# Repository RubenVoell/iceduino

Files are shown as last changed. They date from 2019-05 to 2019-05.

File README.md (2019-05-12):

# A ICE40HX4k Breakout for educational purposes

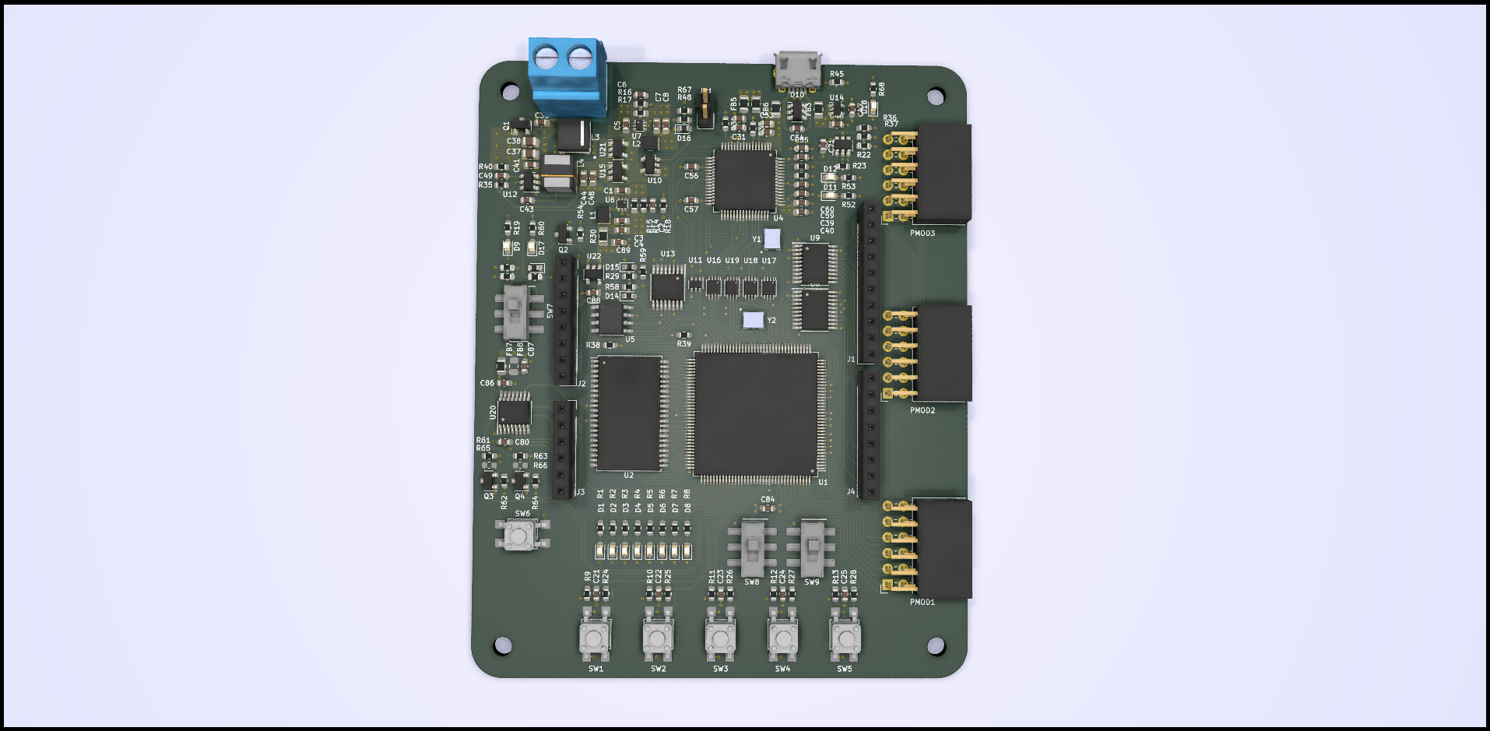
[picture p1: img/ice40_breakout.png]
Rendering of the iCE40HX4K breakout board


The basic idea behind this project is to create a simple breakout of an ICE40 FPGA with some LEDs and Buttons to interact with the FPGA and enough resources to run a simple softcore, like a small RISC-V core. Therefore a SRAM will be added in case the internal memory blocks are not big enough, The configuration SPI flash may be used to store programm data for the softcore. So this board can be used for teaching basic FPGA, microcontroller and CPU architecture topics.

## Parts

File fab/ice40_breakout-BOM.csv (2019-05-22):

Reference | Quantity | Value | Footprint | Datasheet | Description | Digikey | Mfg Name | Mfg Part Num | Spec | DNP | f
C1 C3 C5 C7 C8 C52 C50 C83 C4 C89 C84 C90 C40 C31 C33 C55 C54 C65 C87 C88 C92 C91 | 22 | 10 uF 6,3 V | Capacitor_SMD:C_0603_1608Metric | ~ | CAP CER 10UF 6.3V X5R 0603 | 1276-1119-1-ND | Samsung Electro-Mechanics | CL10A106MQ8NNNC | Any
C17 C18 C19 C20 C53 C51 C16 C15 C14 C13 C12 C11 C10 C9 C43 C21 C22 C23 C24 C25 C42 C74 C45 C85 C39 C30 C32 C66 C56 C57 C58 C59 C60 C64 C67 C68 C69 C71 C72 C70 C61 C62 C63 C77 C78 C75 C76 C81 C82 C79 C27 C28 C29 C26 C73 C86 C80 | 57 | 100nF 6,3 V | Capacitor_SMD:C_0603_1608Metric | ~ | CAP CER 0.1UF 50V X7R 0603 | 1276-1000-1-ND | Samsung Electro-Mechanics | CL10B104KB8NNNC | Any
C2 C6 C49 | 3 | 10pF 6,3 V | Capacitor_SMD:C_0603_1608Metric | ~ | CAP CER 10PF 50V C0G/NP0 0603 | 1276-1027-1-ND | Samsung Electro-Mechanics | CL10C100JB8NNNC | Any
C34 C37 C38 | 3 | 10 uF 25 V | Capacitor_SMD:C_0805_2012Metric | ~ | CAP CER 10UF 25V X5R 0805 | 1276-2891-1-ND | Samsung Electro-Mechanics | CL21A106KAYNNNE | Any
C35 C36 C41 | 3 | 100nF 25 V | Capacitor_SMD:C_0603_1608Metric | ~ | CAP CER 0.1UF 50V X7R 0603 | 1276-1000-1-ND | Samsung Electro-Mechanics | CL10B104KB8NNNC | Any
C47 C46 | 2 | 1 uF 16 V | Capacitor_SMD:C_0603_1608Metric | ~ | CAP CER 1UF 16V X7R 0603 | 1276-6524-1-ND | Samsung Electro-Mechanics | CL10B105MO8NNWC | Any
C48 C44 | 2 | 22 uF 6,3 V | Capacitor_SMD:C_0603_1608Metric | ~ | CAP CER 22UF 6.3V X5R 0603 | 490-7611-1-ND | Murata Electronics North America | GRM188R60J226MEA0D | Any
D10 | 1 | AOZ8904CIL | Package_TO_SOT_SMD:SOT-23-6 | http://aosmd.com/res/data_sheets/AOZ8904CIL.pdf | TVS DIODE 5.5V 18V SOT23-6 | 785-1755-1-ND | Alpha & Omega Semiconductor Inc. | AOZ8904CIL | Spec
D11 | 1 | RX LED | LED_SMD:LED_0603_1608Metric | ~ | LED RED DIFFUSED 1608 SMD | SML-D12U1WT86CT-ND | Rohm Semiconductor | SML-D12U1WT86 | Any
D12 | 1 | TX LED | LED_SMD:LED_0603_1608Metric | ~ | LED RED DIFFUSED 1608 SMD | SML-D12U1WT86CT-ND | Rohm Semiconductor | SML-D12U1WT86 | Any
D13 D16 D14 D15 D19 | 5 | CDBU5020 | Diode_SMD:D_0603_1608Metric | http://www.comchiptech.com/admin/files/product/CDBU0520-HF-RevA797161.pdf | DIODE SCHOTTKY 20V 500MA 0603 | 641-1332-1-ND | Comchip Technology | CDBU0520 | Any
D17 | 1 | DONE | LED_SMD:LED_0603_1608Metric | ~ | LED RED DIFFUSED 1608 SMD | SML-D12U1WT86CT-ND | Rohm Semiconductor | SML-D12U1WT86 | Any
D18 | 1 | USB ON LED | LED_SMD:LED_0603_1608Metric | ~ | LED RED DIFFUSED 1608 SMD | SML-D12U1WT86CT-ND | Rohm Semiconductor | SML-D12U1WT86 | Any
D9 D1 D2 D3 D4 D5 D6 D7 D8 | 9 | LED_ALT | LED_SMD:LED_0603_1608Metric | ~ | LED RED DIFFUSED 1608 SMD | SML-D12U1WT86CT-ND | Rohm Semiconductor | SML-D12U1WT86 | Any
FB1 FB2 FB4 FB5 FB3 FB6 FB7 FB8 | 8 | 330 Ohm | Resistor_SMD:R_0805_2012Metric | https://product.tdk.com/info/en/catalog/datasheets/beads_commercial_power_mpz2012_en.pdf | FERRITE BEAD 330 OHM 0805 1LN | 445-1569-1-ND | TDK Corporation | MPZ2012S331AT000 | Spec
H1 H2 H3 H4 | 4 | MountingHole | MountingHole:MountingHole_3mm | ~
J1 | 1 | Conn_01x10 | Connector_PinSocket_2.54mm:PinSocket_1x10_P2.54mm_Vertical | ~ | CONN HDR 10POS 0.1 GOLD PCB | 732-2859-ND | Wurth Electronics Inc. | 61301011821 | Any
J2 J4 | 2 | Conn_01x08 | Connector_PinSocket_2.54mm:PinSocket_1x08_P2.54mm_Vertical | ~ | CONN HDR 8POS 0.1 GOLD PCB | S7041-ND | Sullins Connector Solutions | PPPC081LFBN-RC | Any
J3 | 1 | Conn_01x06 | Connector_PinSocket_2.54mm:PinSocket_1x06_P2.54mm_Vertical | ~ | CONN HDR 6POS 0.1 GOLD PCB | S7039-ND | Sullins Connector Solutions | PPPC061LFBN-RC | Any
J5 | 1 | USB_B_Micro | footprints:Amphenol_microUSB_B_footprint | http://www.amphenol-icc.com/media/wysiwyg/files/drawing/10118194.pdf | CONN RCPT USB2.0 MICRO B SMD R/A | 609-4618-1-ND | Amphenol ICC (FCI) | 10118194-0001LF | Spec
J6 | 1 | 7-17 V IN | TerminalBlock:TerminalBlock_bornier-2_P5.08mm | https://www.cui.com/product/resource/digikeypdf/tb007-508.pdf | ERMINAL BLOCK, SCREW TYPE, 5.08 | 102-6203-ND | CUI Inc. | TB007-508-02BE
JP1 | 1 | VBUS_EN | Connector_PinHeader_2.54mm:PinHeader_1x02_P2.54mm_Vertical | ~
L1 L2 | 2 | 1u | footprints:L_1008_2520Metric_2.5x2mm_footprint | https://www.yuden.co.jp/productdata/catalog/wound10_e.pdf | FIXED IND 1UH 2.7A 59 MOHM SMD | 587-3225-1-ND | Taiyo Yuden | MAMK2520T1R0M | Spec
L3 | 1 | L_DLW5BTM | footprints:L_Murata_DLW5BTM_5.00x5.00mm_footprint | https://www.murata.com/en-us/products/productdata/8796761587742/EFLC0025.pdf | CMC 5A 2LN 250 OHM SMD | 490-11111-1-ND | Murata Electronics North America | DLW5BTM251SQ2L | Spec
L4 | 1 | 4,7 uH | Inductor_SMD:L_Taiyo-Yuden_NR-50xx | ~ | FIXED IND 4.7UH 3.1A 37.7 MOHM | 587-2373-1-ND | Taiyo Yuden | NR5040T4R7N | Spec
PMOD2 PMOD3 PMOD1 | 3 | Conn_02x06_Odd_Even | Connector_PinSocket_2.54mm:PinSocket_2x06_P2.54mm_Horizontal | ~ | CONN HDR 12POS 0.1 GOLD PCB R/A | S5559-ND | Sullins Connector Solutions | PPPC062LJBN-RC | Any
Q1 | 1 | DMP3099L-7 | Package_TO_SOT_SMD:SOT-23 | https://www.diodes.com/assets/Datasheets/DMP3099L.pdf | MOSFET P-CH 30V SOT23 | DMP3099L-7DICT-ND | Diodes Incorporated | DMP3099L-7 | Spec
Q2 Q4 Q3 | 3 | Q_NMOS_GSD | Package_TO_SOT_SMD:SOT-23 | https://www.diodes.com/assets/Datasheets/DMN65D8L.pdf | MOSFET N-CH 60V 310MA SOT23 | DMN65D8L-7DICT-ND | Diodes Incorporated | DMN65D8L-7 | Spec
R14 R15 | 2 | 100k 1% | Resistor_SMD:R_0603_1608Metric | ~ | RES SMD 100K OHM 1% 1/10W 0603 | 311-100KHRCT-ND | Yageo | RC0603FR-07100KL | Any
R16 | 1 | 220k 1% | Resistor_SMD:R_0603_1608Metric | ~ | RES SMD 220K OHM 1% 1/10W 0603 | 311-220KHRCT-ND | Yageo | RC0603FR-07220KL | Any
R17 | 1 | 48,7k 1% | Resistor_SMD:R_0603_1608Metric | ~ | RES SMD 48.7K OHM 1% 1/10W 0603 | 311-48.7KHRCT-ND | Yageo | RC0603FR-0748K7L | Any
R18 R47 R48 R67 R20 R21 R22 R43 R44 R38 R39 R37 R45 R59 R58 R29 R54 R71 | 18 | 10k | Resistor_SMD:R_0603_1608Metric | ~ | RES 10K OHM 5% 1/10W 0603 | RMCF0603JT10K0CT-ND | Stackpole Electronics Inc | RMCF0603JT10K0 | Any
R19 R1 R2 R3 R4 R5 R6 R7 R8 R52 R53 R68 R60 | 13 | 560 | Resistor_SMD:R_0603_1608Metric | ~ | RES 560 OHM 5% 1/8W 0603 | 2019-RK73B1JTTD561JCT-ND | KOA Speer Electronics, Inc. | RK73B1JTTD561J | Any
R23 R34 | 2 | 2,2k | Resistor_SMD:R_0603_1608Metric | ~ | RES SMD 2.2K OHM 1% 1/10W 0603 | 311-2.20KHRCT-ND | Yageo | RC0603FR-072K2L | Any
R24 R25 R26 R27 R28 R56 R57 | 7 | 470 | Resistor_SMD:R_0603_1608Metric | ~ | RES 470 OHM 5% 1/10W 0603 | RMCF0603JT470RCT-ND | Stackpole Electronics Inc | RMCF0603JT470R | Any
R30 | 1 | 0 | Resistor_SMD:R_0805_2012Metric | ~ | RES SMD 0 OHM JUMPER 1/8W 0805 | 311-0.0ARCT-ND | Yageo | RC0805JR-070RL | Any
R33 | 1 | 12k | Resistor_SMD:R_0603_1608Metric | ~ | RES SMD 12K OHM 5% 1/10W 0603 | 311-12KGRCT-ND | Yageo | RC0603JR-0712KL | Any
R35 | 1 | 54k9 1% | Resistor_SMD:R_0603_1608Metric | ~ | RES SMD 54.9K OHM 1% 1/10W 0603 | 311-54.9KHRCT-ND | Yageo | RC0603FR-0754K9L | Any
R36 | 1 | 4k7 | Resistor_SMD:R_0603_1608Metric | ~ |  |  |  |  |  | DNP
R40 | 1 | 10k 1% | Resistor_SMD:R_0603_1608Metric | ~ | RES SMD 10K OHM 1% 1/10W 0603 | 311-10.0KHRCT-ND | Yageo | RC0603FR-0710KL | Any
R42 R41 | 2 | 100 | Resistor_SMD:R_0603_1608Metric | ~ | RES 100 OHM 1% 1/10W 0603 | RMCF0603FT100RCT-ND | Stackpole Electronics Inc | RMCF0603FT100R | Any
R46 | 1 | 33k | Resistor_SMD:R_0603_1608Metric | ~ | RES SMD 33K OHM 5% 1/10W 0603 | 311-33KGRCT-ND | Yageo | RC0603JR-0733KL | Any
R49 | 1 | 22k | Resistor_SMD:R_0603_1608Metric | ~ | RES SMD 22K OHM 1% 1/10W 0603 | 311-22.0KHRCT-ND | Yageo | RC0603FR-0722KL | Any
R55 | 1 | 270k 1% | Resistor_SMD:R_0603_1608Metric | ~ | RES SMD 270K OHM 1% 1/10W 0603 | 311-270KHRCT-ND | Yageo | RC0603FR-07270KL | Any
R65 R66 | 2 | 0 | Resistor_SMD:R_0603_1608Metric | ~ |  |  |  |  |  | Do Not Place
R69 | 1 | 30k 1% | Resistor_SMD:R_0603_1608Metric | ~ | RES SMD 30K OHM 1% 1/10W 0603 | 311-30.0KHRCT-ND | Yageo | RC0603FR-0730KL | Any
R70 | 1 | 1k | Resistor_SMD:R_0603_1608Metric | ~ | RES SMD 1K OHM 5% 1/10W 0603 | 311-1.0KGRCT-ND | Yageo | RC0603JR-071KL | Any
R9 R11 R12 R13 R10 R50 R51 R31 R32 R63 R64 R61 R62 | 13 | 4,7k | Resistor_SMD:R_0603_1608Metric | ~ | RES 4.7K OHM 5% 1/10W 0603 | RMCF0603JT4K70CT-ND | Stackpole Electronics Inc | RMCF0603JT4K70 | Any
RV1 RV2 | 2 | CG0603MLA-18KE | Resistor_SMD:R_0603_1608Metric | https://www.bourns.com/docs/Product-Datasheets/MLA.pdf | VARISTOR 22V 30A 0603 | CG0603MLA-18KECT-ND | Bourns Inc. | CG0603MLA-18KE | Spec
SW3 SW4 SW5 SW2 SW1 SW6 | 6 | SW_Push | footprints:SW_SPST_TL3305A | http://spec_sheets.e-switch.com/specs/P010468.pdf | SWITCH TACTILE SPST-NO 50MA 12V | EG5350CT-ND | E-Switch | TL3305AF160QG | Spec
SW7 SW8 SW9 | 3 | JS202011SCQN | footprints:SW_SLIDE_DPDT_Slide_CK_JS202011SCQN_W3mm_P2.5mm_footprint | https://www.ckswitches.com/media/1422/js.pdf | SWITCH SLIDE DPDT 300MA 6V | 401-2002-1-ND | C&K | JS202011SCQN | Spec
U1 | 1 | ICE40HX4K-TQ144 | Package_QFP:TQFP-144_20x20mm_P0.5mm |  | IC FPGA 107 I/O 144TQFP | 220-1572-ND | Lattice Semiconductor Corporation | ICE40HX4K-TQ144 | Spec
U10 U21 U15 U22 U23 | 5 | MAX40200AUK | Package_TO_SOT_SMD:SOT-23-5 | https://datasheets.maximintegrated.com/en/ds/MAX40200.pdf | IC DIODE CURRENT SWITCH SOT23-5 | MAX40200AUK+TCT-ND | Maxim Integrated | MAX40200AUK+T | Spec
U11 | 1 | SN74LVC2G07DCKR | Package_TO_SOT_SMD:SOT-363_SC-70-6 | http://www.ti.com/lit/ds/symlink/sn74lvc2g07.pdf | IC BUF NON-INVERT 5.5V SC70-6 | 296-13495-1-ND | Texas Instruments | SN74LVC2G07DCKR | Spec
U12 | 1 | TPS562201 | Package_TO_SOT_SMD:SOT-23-6 | http://www.ti.com/lit/ds/symlink/tps562201.pdf | Buck Switching Regulator IC Positive Adjustable 0.768V 1 Output 2A SOT-23-6 Thin, TSOT-23-6 | 296-44397-1-ND | Texas Instruments | TPS562201DDCR | Spec
U13 | 1 | SN74AXC4T245PWR | Package_SO:TSSOP-16_4.4x5mm_P0.65mm | http://www.ti.com/lit/ds/symlink/sn74axc4t245.pdf | LOGIC GATES AND INVERTERS | 296-53472-1-ND | Texas Instruments | SN74AXC4T245PWR | Spec
U14 | 1 | MIC5365-3.3YC5 | Package_TO_SOT_SMD:SOT-353_SC-70-5 | http://ww1.microchip.com/downloads/en/DeviceDoc/mic5365.pdf | IC REG LINEAR 3.3V 150MA SC70-5 | 576-3193-1-ND | Microchip Technology | MIC5365-3.3YC5-TR | Spec
U16 U17 U19 U18 | 4 | SN74LVC2T45DCUR | Package_SO:VSSOP-8_2.4x2.1mm_P0.5mm | http://www.ti.com/lit/ds/symlink/sn74lvc2t45.pdf | IC TRNSLTR BIDIRECTIONAL US8 | 296-17014-1-ND | Texas Instruments | SN74LVC2T45DCUR | Spec
U2 | 1 | IS61WV5128EDBLL-10TLI | Package_SO:TSOP-II-44_10.16x18.41mm_P0.8mm | http://www.issi.com/WW/pdf/61-64WV5128EDBLL.pdf | C SRAM 4M PARALLEL 44TSOP2 | 706-1147-ND | ISSI, Integrated Silicon Solution Inc | IS61WV5128EDBLL-10TLI | Spec
U20 | 1 | MAX11614 | Package_SO:QSOP-16_3.9x4.9mm_P0.635mm | https://datasheets.maximintegrated.com/en/ds/MAX11612-MAX11617.pdf | IC ADC SERIAL 12BIT 8CH 16-QSOP | MAX11614EEE+-ND | Maxim Integrated | MAX11614EEE+ | Spec
U3 | 1 | 93LCxxBT-I_OT | Package_TO_SOT_SMD:SOT-23-6 | http://ww1.microchip.com/downloads/en/DeviceDoc/21794G.pdf | IC EEPROM 2K SPI 2MHZ SOT23-6 | 93LC56BT-I/OTCT-ND | Microchip Technology | 93LC56BT-I/OT | Spec
U4 | 1 | FT2232H | Package_QFP:LQFP-64_10x10mm_P0.5mm | http://www.ftdichip.com/Products/ICs/FT2232H.html | IC USB HS DUAL UART/FIFO 64-LQFP | 768-1024-1-ND | FTDI, Future Technology Devices International Ltd | FT2232HL-REEL | Spec
U5 | 1 | IS25LP080D | Package_SO:SO-8_3.9x4.9mm_P1.27mm | http://www.issi.com/WW/pdf/25LP-WP080D.pdf | IC FLASH 8M SPI 133MHZ 8SOP | 706-1580-ND | ISSI, Integrated Silicon Solution Inc | IS25LP080D-JNLE | Spec
U6 U7 | 2 | TLV62568APDRLR | footprints:Texas_DRL_SOT-563_1.6x1.6mm_0.5mm-pitch_footprint | http://www.ti.com/lit/ds/symlink/tlv62568a.pdf | IC REG BUCK ADJUSTABLE 1A SOT563 | 296-51691-1-ND | Texas Instruments | TLV62568APDRLR | Spec
U9 U8 | 2 | TXS0108EPW | Package_SO:TSSOP-20_4.4x6.5mm_P0.65mm | www.ti.com/lit/ds/symlink/txs0108e.pdf | IC TRNSLTR BIDIRECTIONAL 20TSSOP | 296-23011-1-ND | Texas Instruments | TXS0108EPWR | Spec
Y1 | 1 | ECS-3225S33-120-FN-TR | footprints:Y_ECS-3225S_3.2x2.5mm_footprint | https://www.ecsxtal.com/store/pdf/ECS-3225S.pdf | XTAL OSC XO 12.0000MHZ HCMOS SMD | XC2217CT-ND | ECS Inc. | ECS-3225S33-120-FN-TR | Spec |  | 12 MHz <=30 ppm
Y2 | 1 | ECS-3225S33-500-FN-TR | footprints:Y_ECS-3225S_3.2x2.5mm_footprint | https://www.ecsxtal.com/store/pdf/ECS-3225S.pdf | XTAL OSC XO 50.0000MHZ HCMOS SMD | XC2226CT-ND | ECS Inc. | ECS-3225S33-500-FN-TR | Spec |  | 50 MHz

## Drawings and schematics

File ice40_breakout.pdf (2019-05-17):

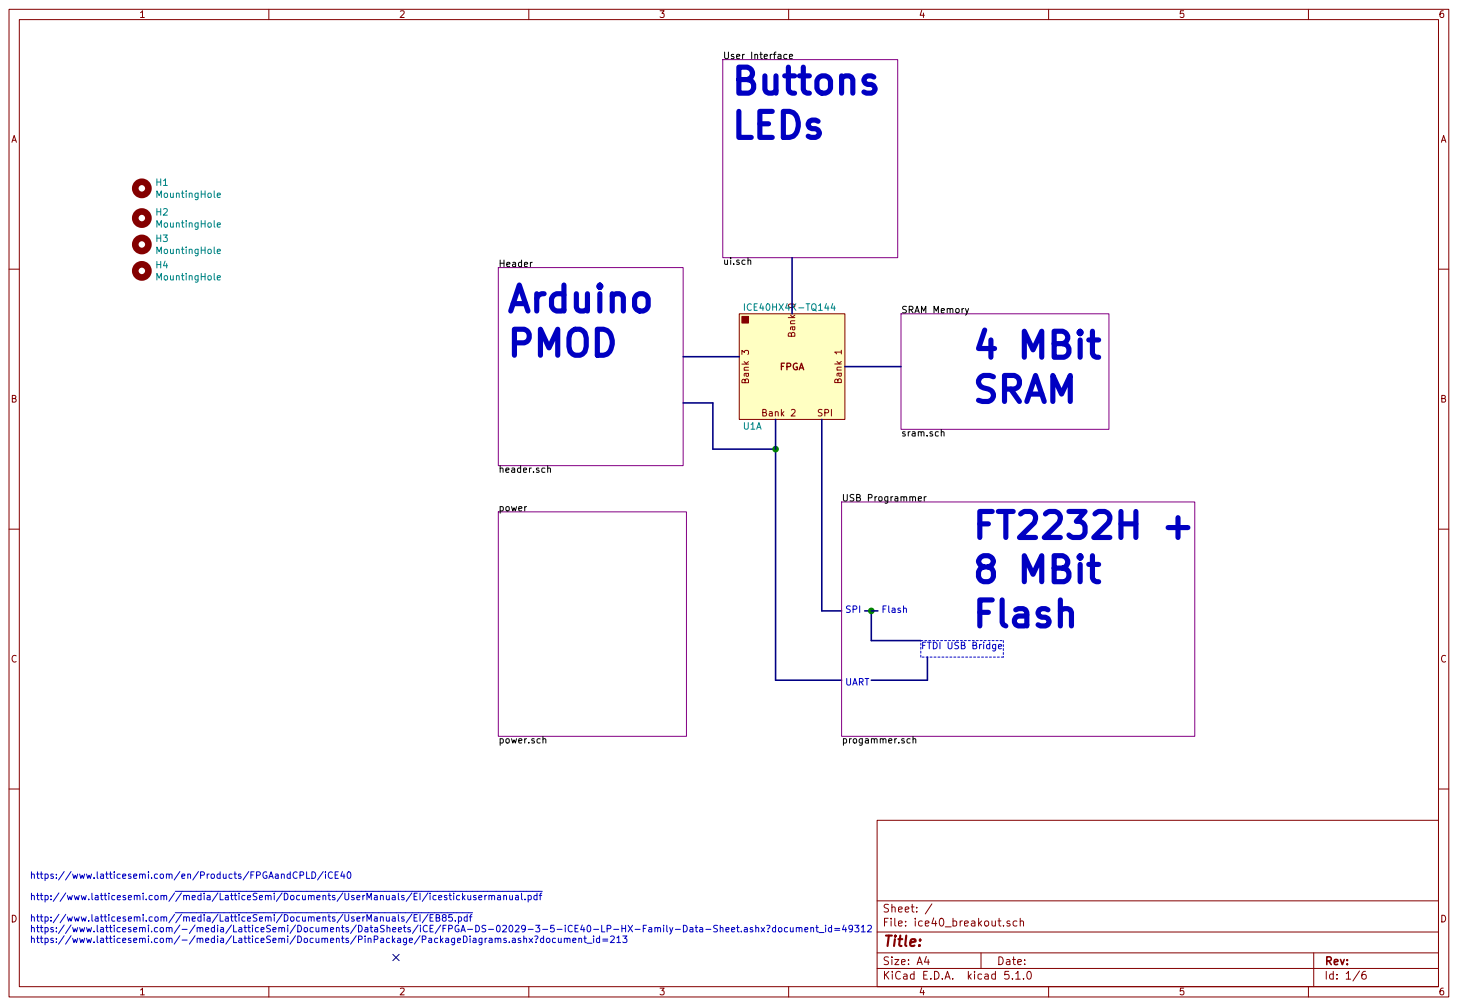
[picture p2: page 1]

https://www.latticesemi.com/en/Products/FPGAandCPLD/iCE40

http://www.latticesemi.com//media/LatticeSemi/Documents/UserManuals/EI/icestickusermanual.pdf

http://www.latticesemi.com//media/LatticeSemi/Documents/UserManuals/EI/EB85.pdf
https://www.latticesemi.com/-/media/LatticeSemi/Documents/DataSheets/iCE/FPGA-DS-02029-3-5-iCE40-LP-HX-Family-Data-Sheet.ashx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
https://www.latticesemi.com/-/media/LatticeSemi/Documents/PinPackage/PackageDiagrams.ashx?document_id=213

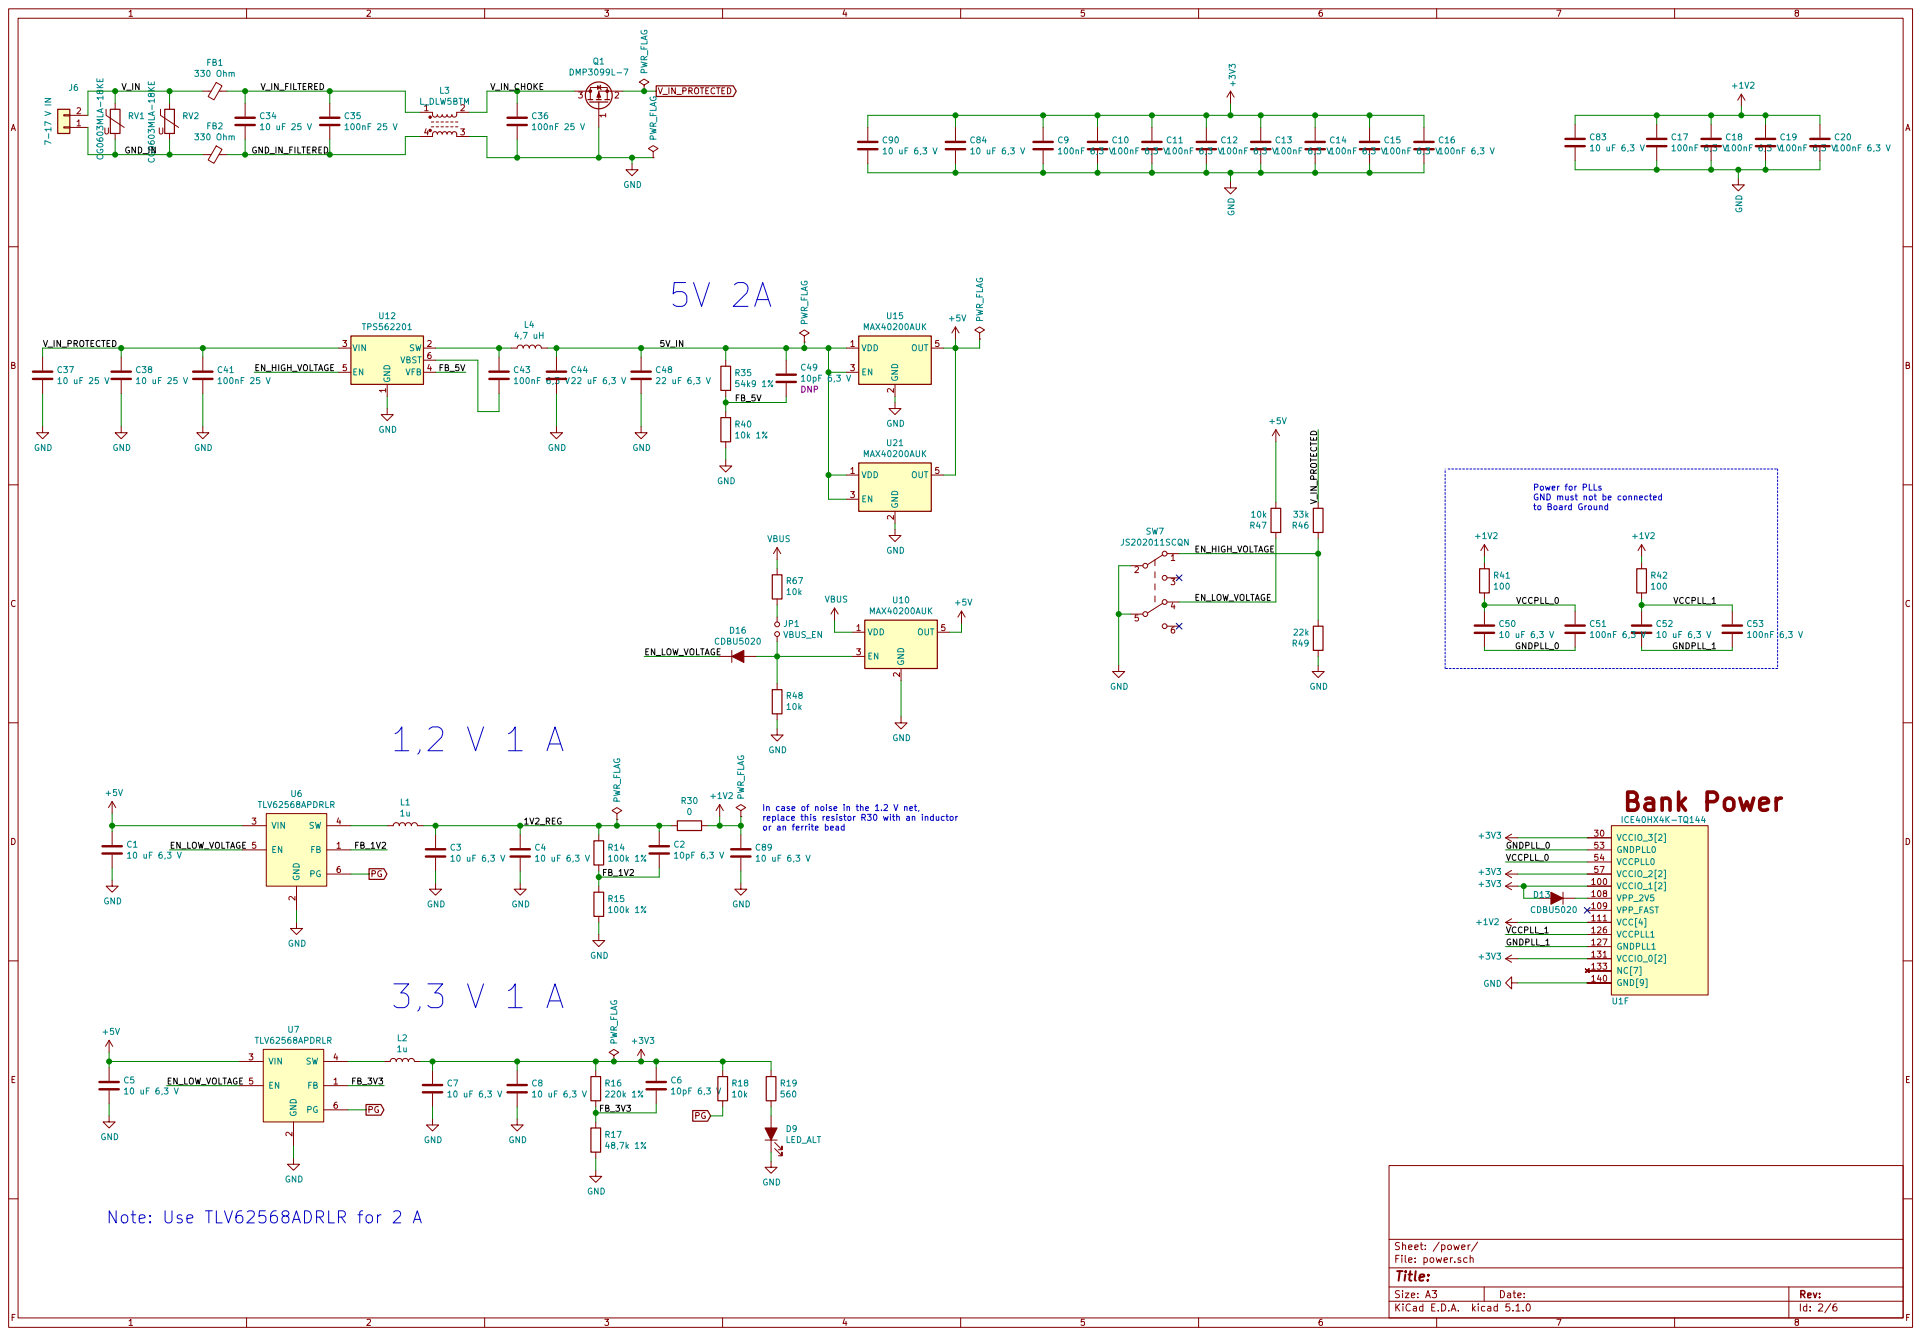
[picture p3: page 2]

1 SW 2 VIN 3 VFB 4 EN 5 VBST 6 U12 TPS562201 PWR_FLAG

2 EN 3 OUT 5 U21 MAX40200AUK GND GND

2 VIN 3 SW 4 EN 5 PG 6 U6 TLV62568APDRLR

In case of noise in the 1.2 V net, replace this resistor R30 with an inductor or an ferrite bead 1V2_REG

2 VIN 3 SW 4 EN 5 PG 6 U7 TLV62568APDRLR

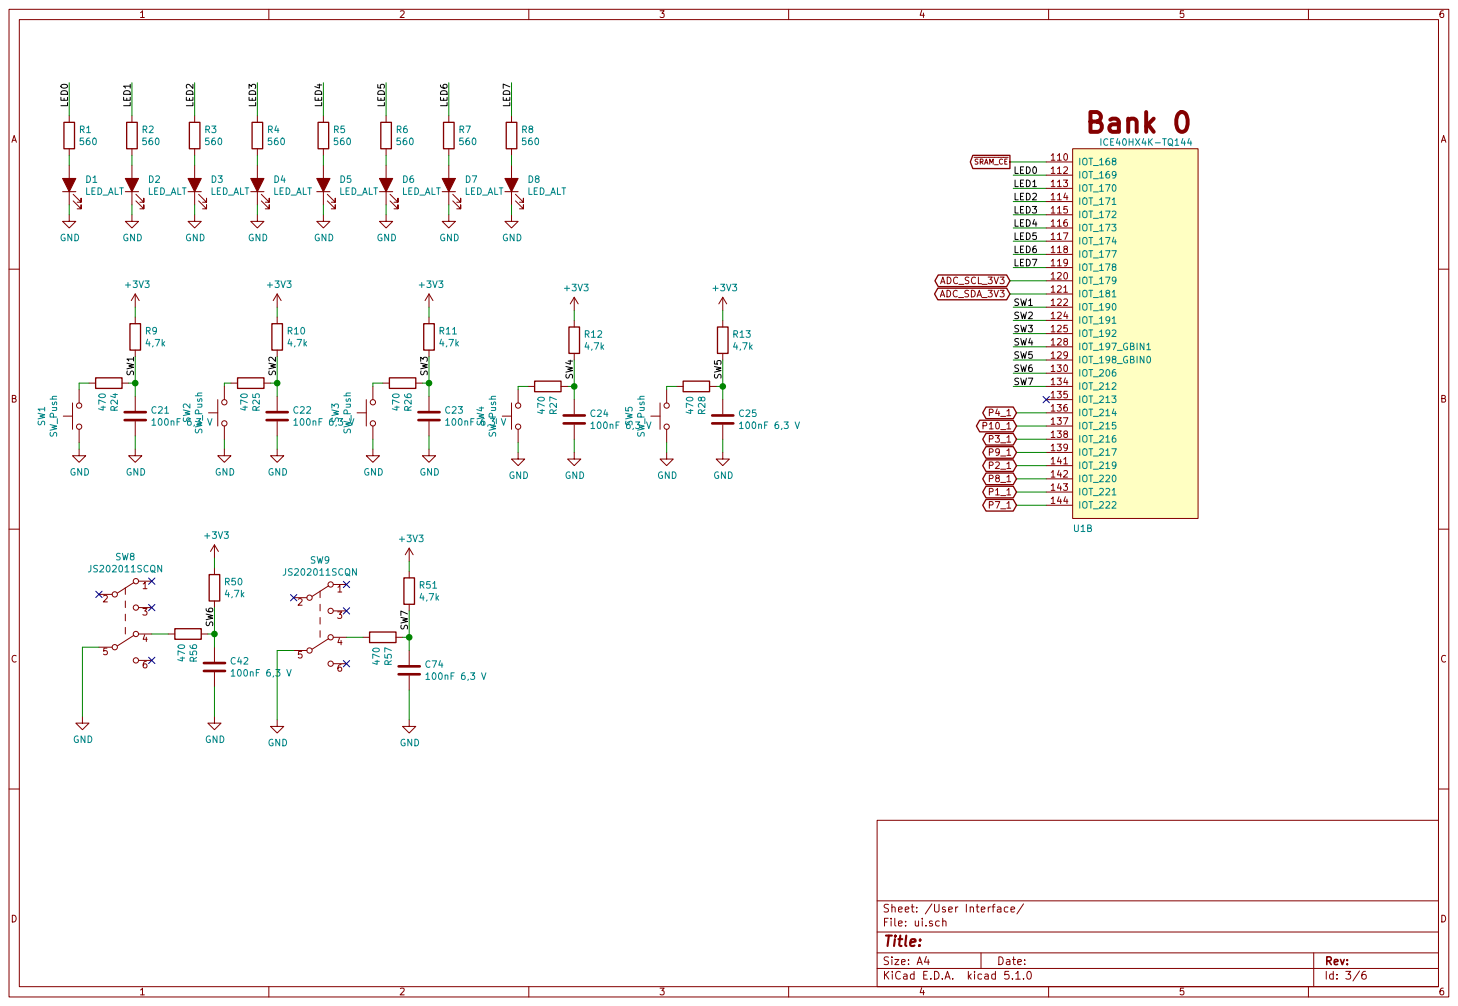
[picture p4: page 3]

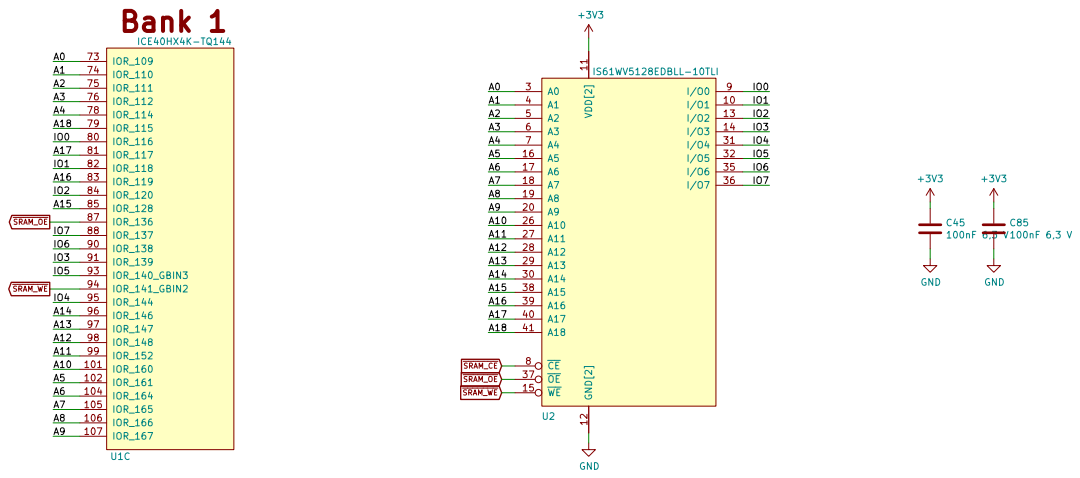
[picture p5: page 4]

Id: 4/6 Title: File: sram.sch Sheet: /SRAM Memory/

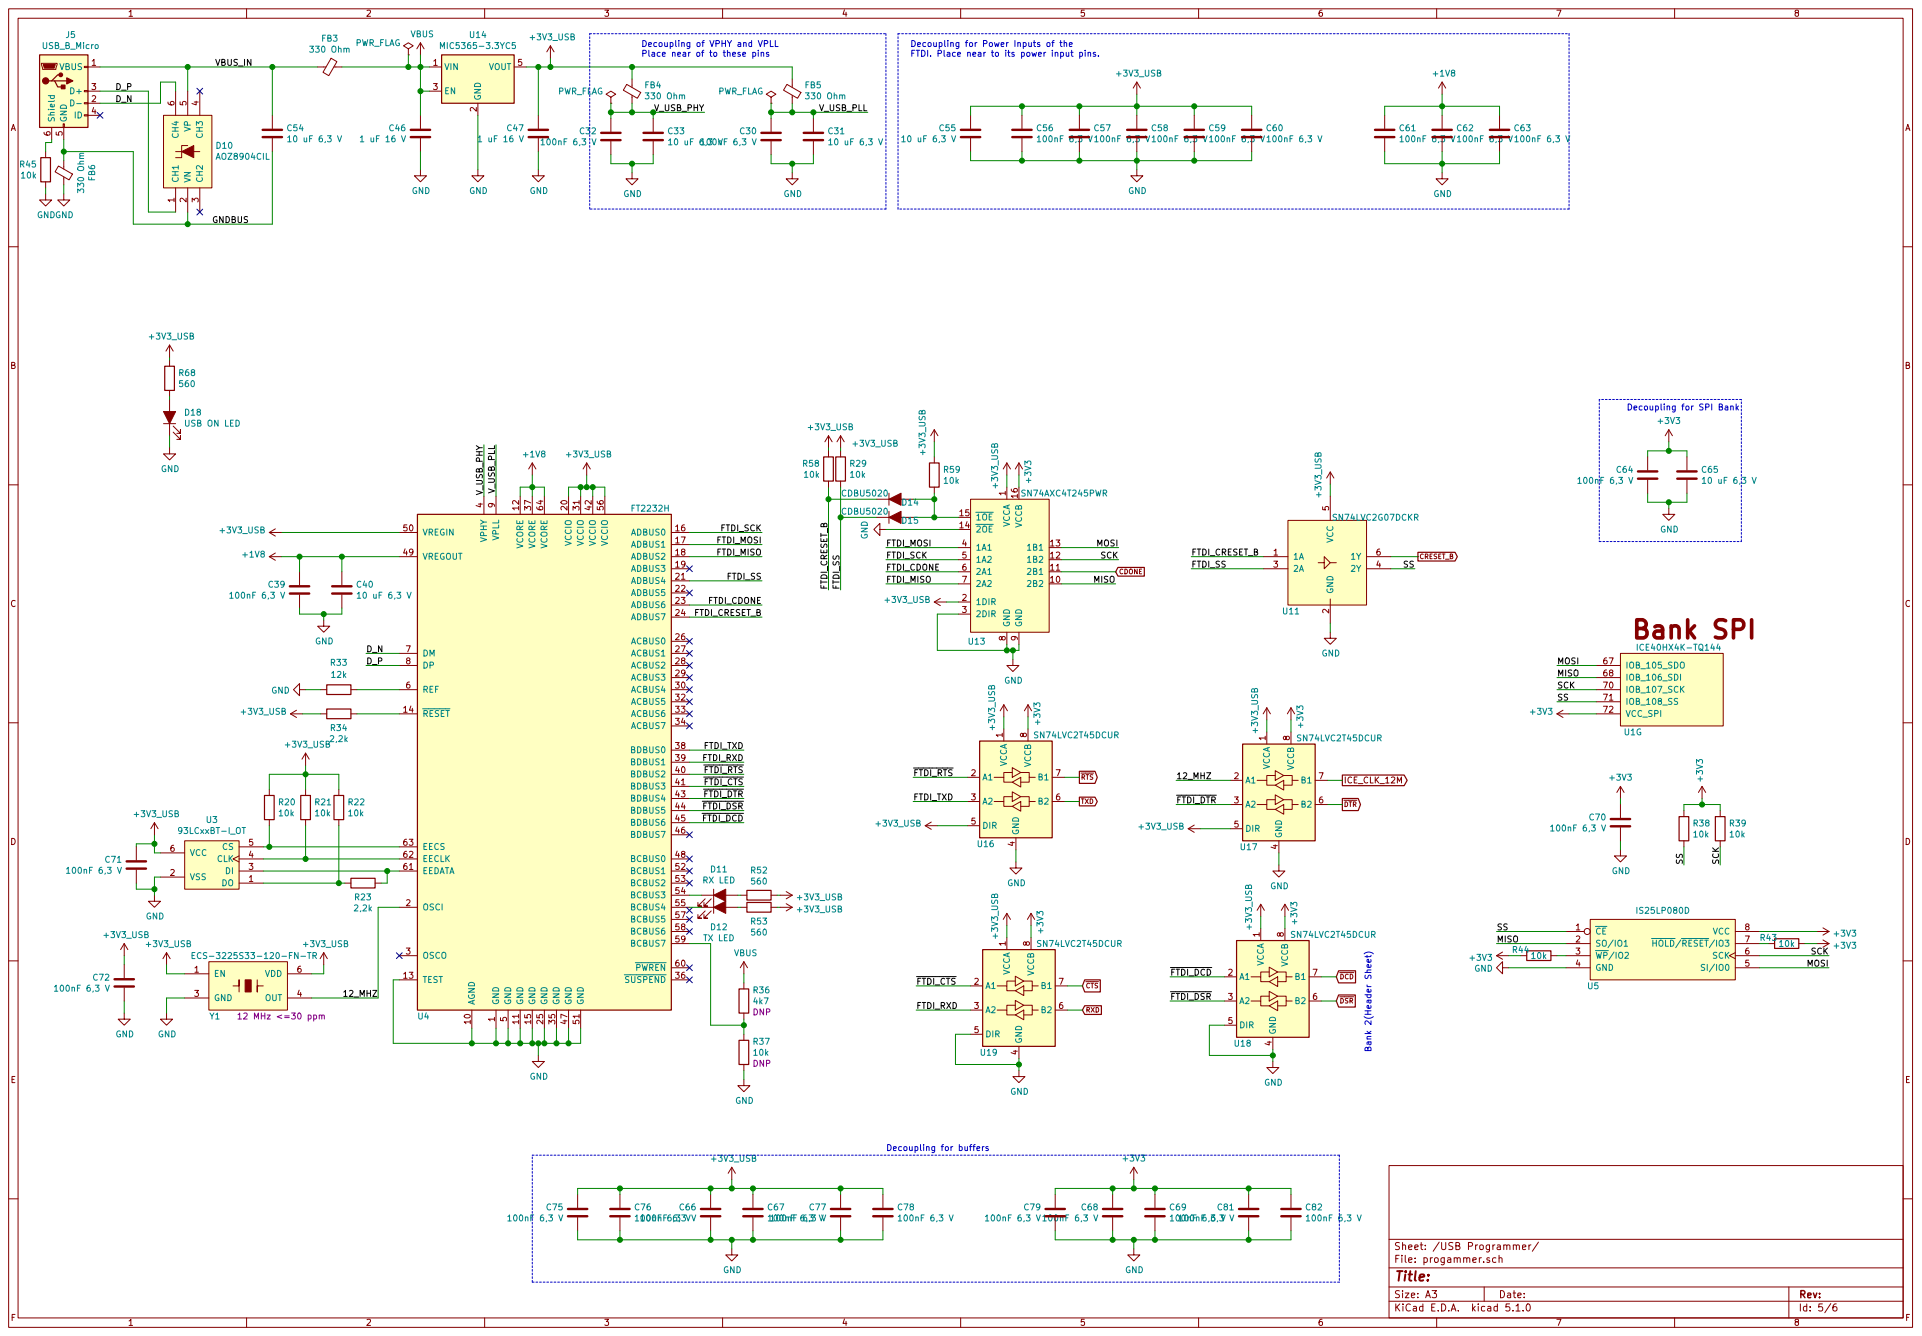
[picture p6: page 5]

2 EN 3 VOUT 5 U14 MIC5365-3.3YC5 VBUS GND

Decoupling of VPHY and VPLL
Place near of to these pins

Decoupling for Power Inputs of the

Decoupling for SPI Bank C71

1 AGND 10 GND 11 VCORE 12 TEST 13 RESET 14 GND 15 ADBUS0 16 ADBUS1 17 ADBUS2 18 ADBUS3 19 OSCI 2 VCCIO 20 ADBUS4 21 ADBUS5 22 ADBUS6 23 ADBUS7 24 GND 25 ACBUS0 26 ACBUS1 27 ACBUS2 28 ACBUS3 29 OSCO 3 ACBUS4 30 VCCIO 31 ACBUS5 32 ACBUS6 33 ACBUS7 34 GND 35 SUSPEND 36 VCORE 37 BDBUS0 38 BDBUS1 39 VPHY

4 BDBUS2 40 BDBUS3 41 VCCIO 42 BDBUS4 43 BDBUS5 44 BDBUS6 45 BDBUS7 46 GND 47 BCBUS0 48 VREGOUT 49 GND

5 VREGIN 50 GND 51 BCBUS1 52 BCBUS2 53 BCBUS3 54 BCBUS4 55 VCCIO 56 BCBUS5 57 BCBUS6 58 BCBUS7 59 REF 6 PWREN 60 EEDATA 61 EECLK 62 EECS 63 VCORE 64 DM 7 DP 8 VPLL

Sheet: /USB Programmer/ GND

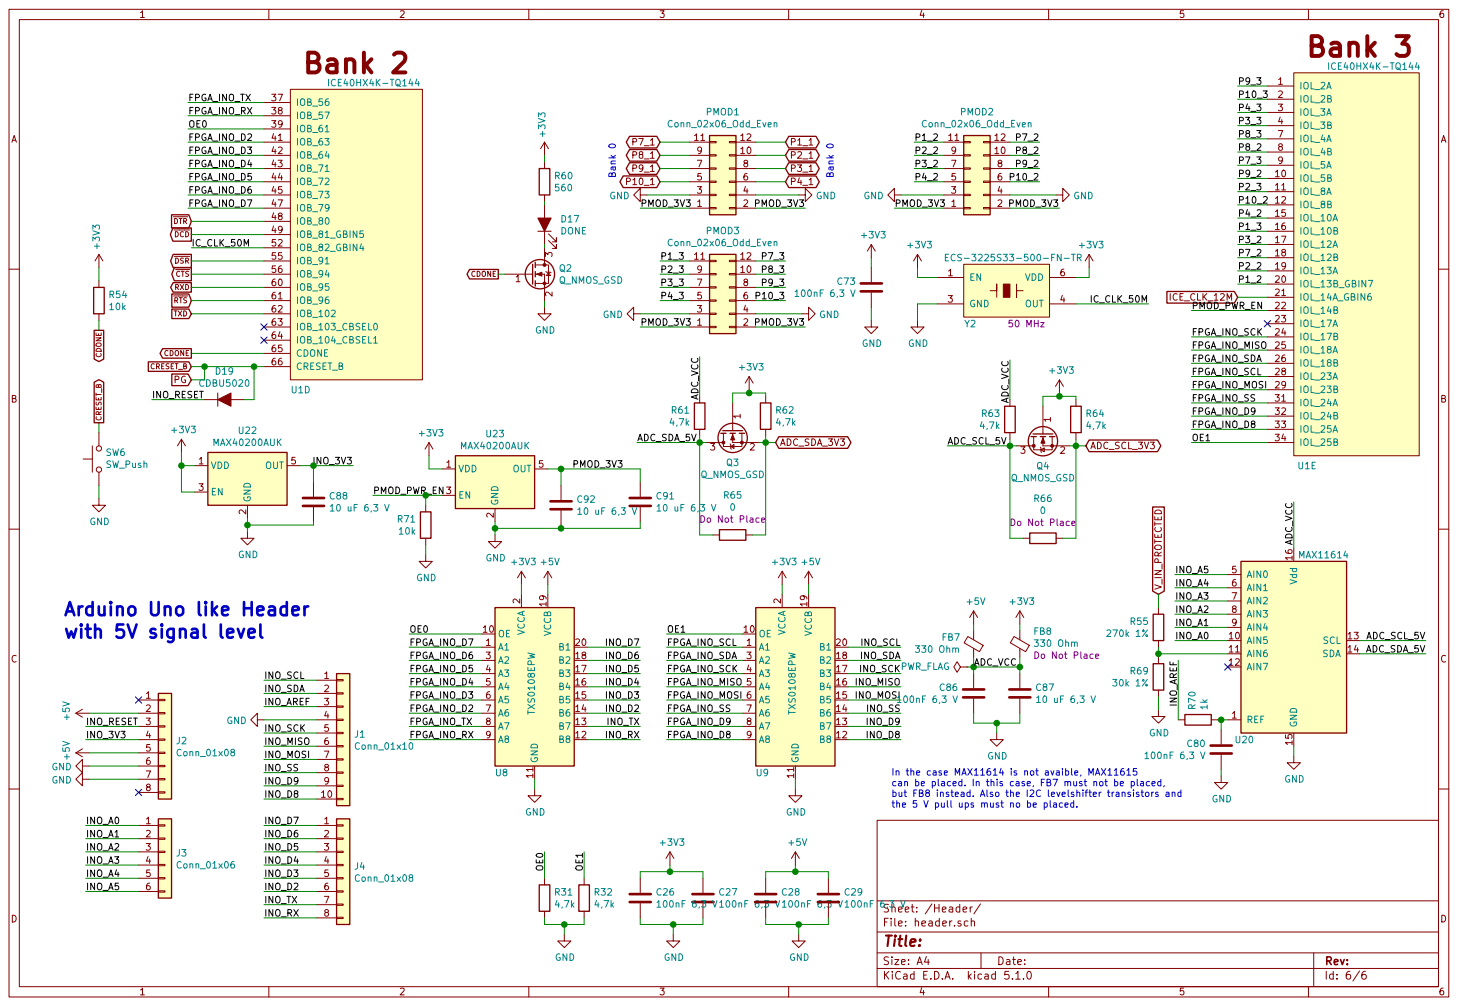
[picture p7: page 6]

FPGA_INO_D2 FPGA_INO_D3 FPGA_INO_D4 FPGA_INO_D5 FPGA_INO_D6 FPGA_INO_D7 Arduino Uno like Header

In the case MAX11614 is not avaible, MAX11615
can be placed. In this case, FB7 must not be placed, but FB8 instead. Also the I2C levelshifter transistors and

the 5 V pull ups must no be placed.

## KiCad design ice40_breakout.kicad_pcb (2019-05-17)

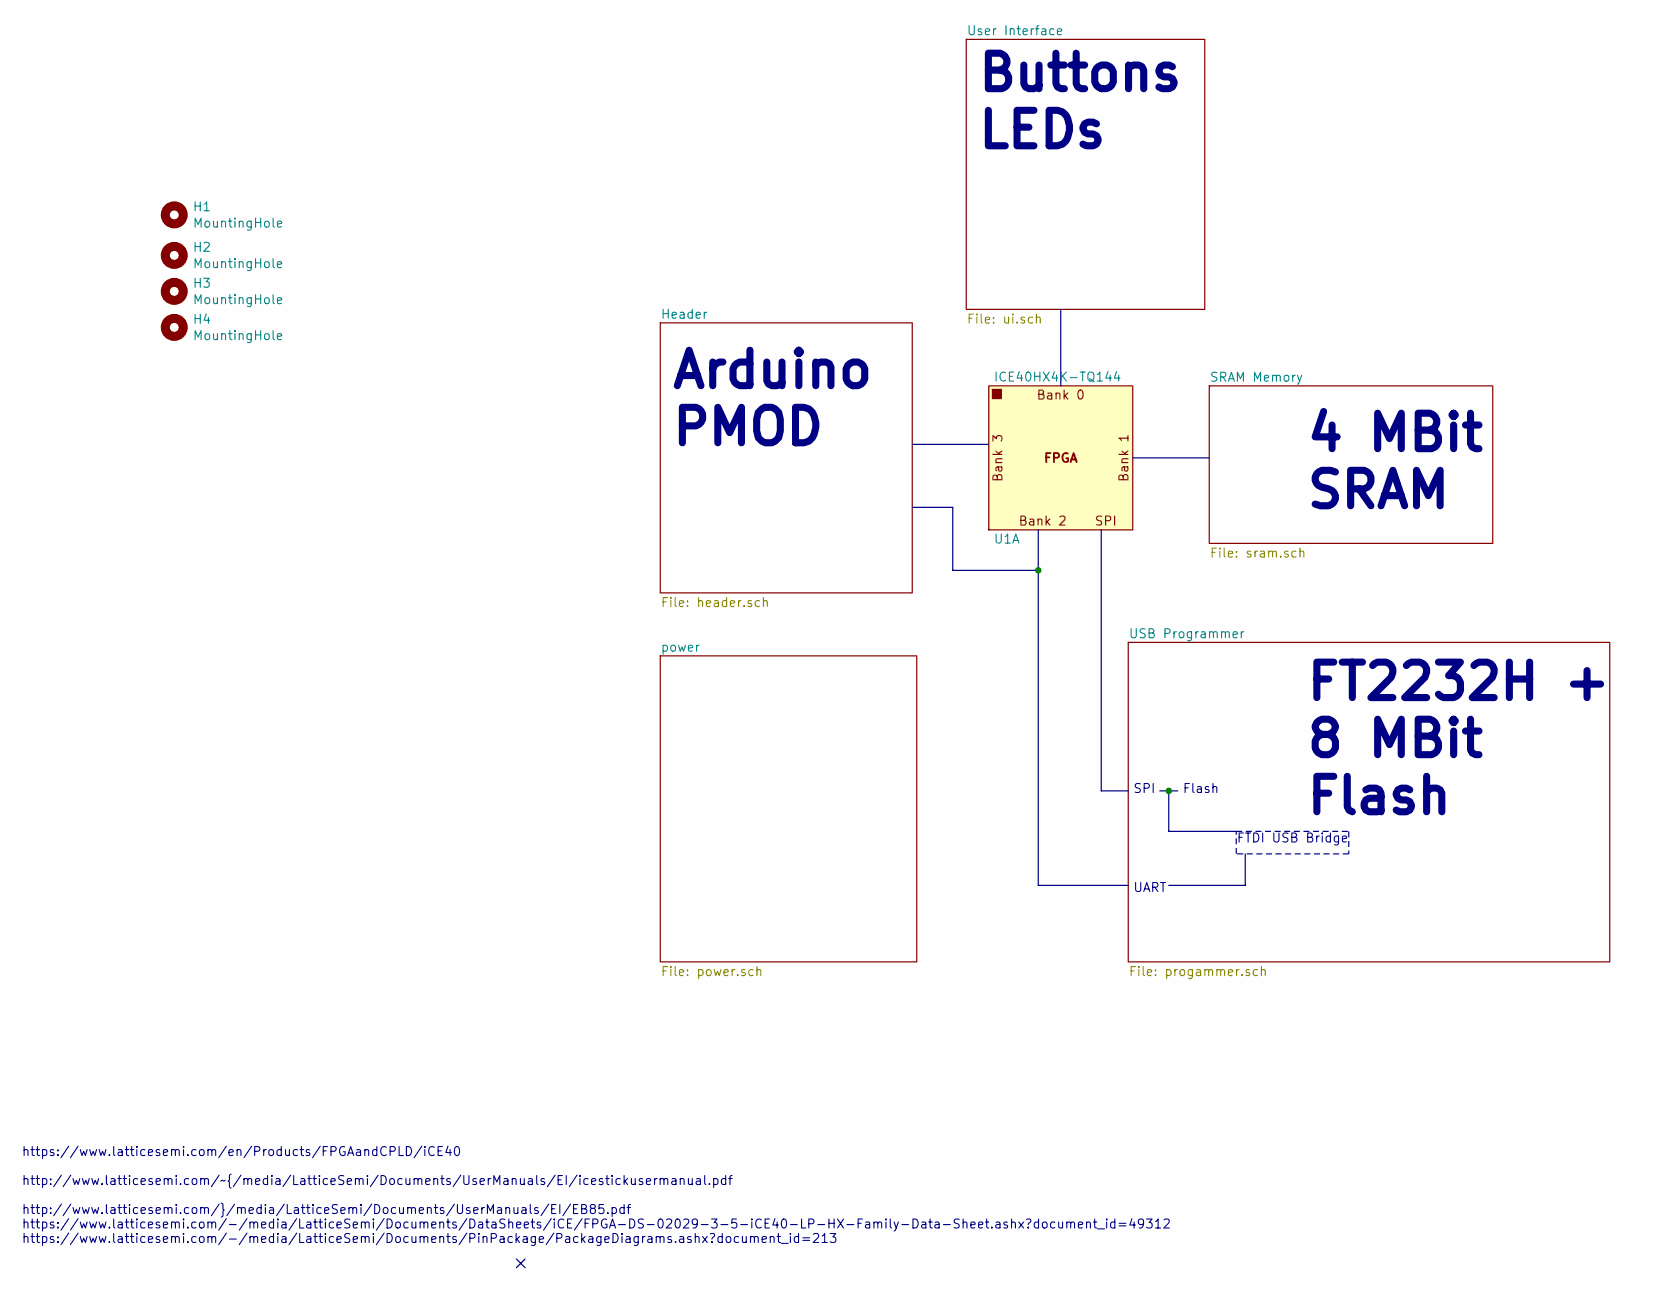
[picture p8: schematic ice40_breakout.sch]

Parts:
H1, H2, H3, H4: MountingHole; MountingHole_3mm
U1: ICE40HX4K-TQ144; TQFP-144_20x20mm_P0.5mm; Mfg Part Num ICE40HX4K-TQ144; Digikey 220-1572-ND

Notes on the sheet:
https://www.latticesemi.com/en/Products/FPGAandCPLD/iCE40 http://www.latticesemi.com/~/media/LatticeSemi/Documents/UserManuals/EI/icestickusermanual.pdf http://www.latticesemi.com/~/media/LatticeSemi/Documents/UserManuals/EI/EB85.pdf https://www.latticesemi.com/-/media/LatticeSemi/Documents/DataShe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
SPI
Flash
UART
FTDI USB Bridge
4 MBit SRAM
Arduino PMOD
Buttons LEDs
FT2232H + 8 MBit Flash

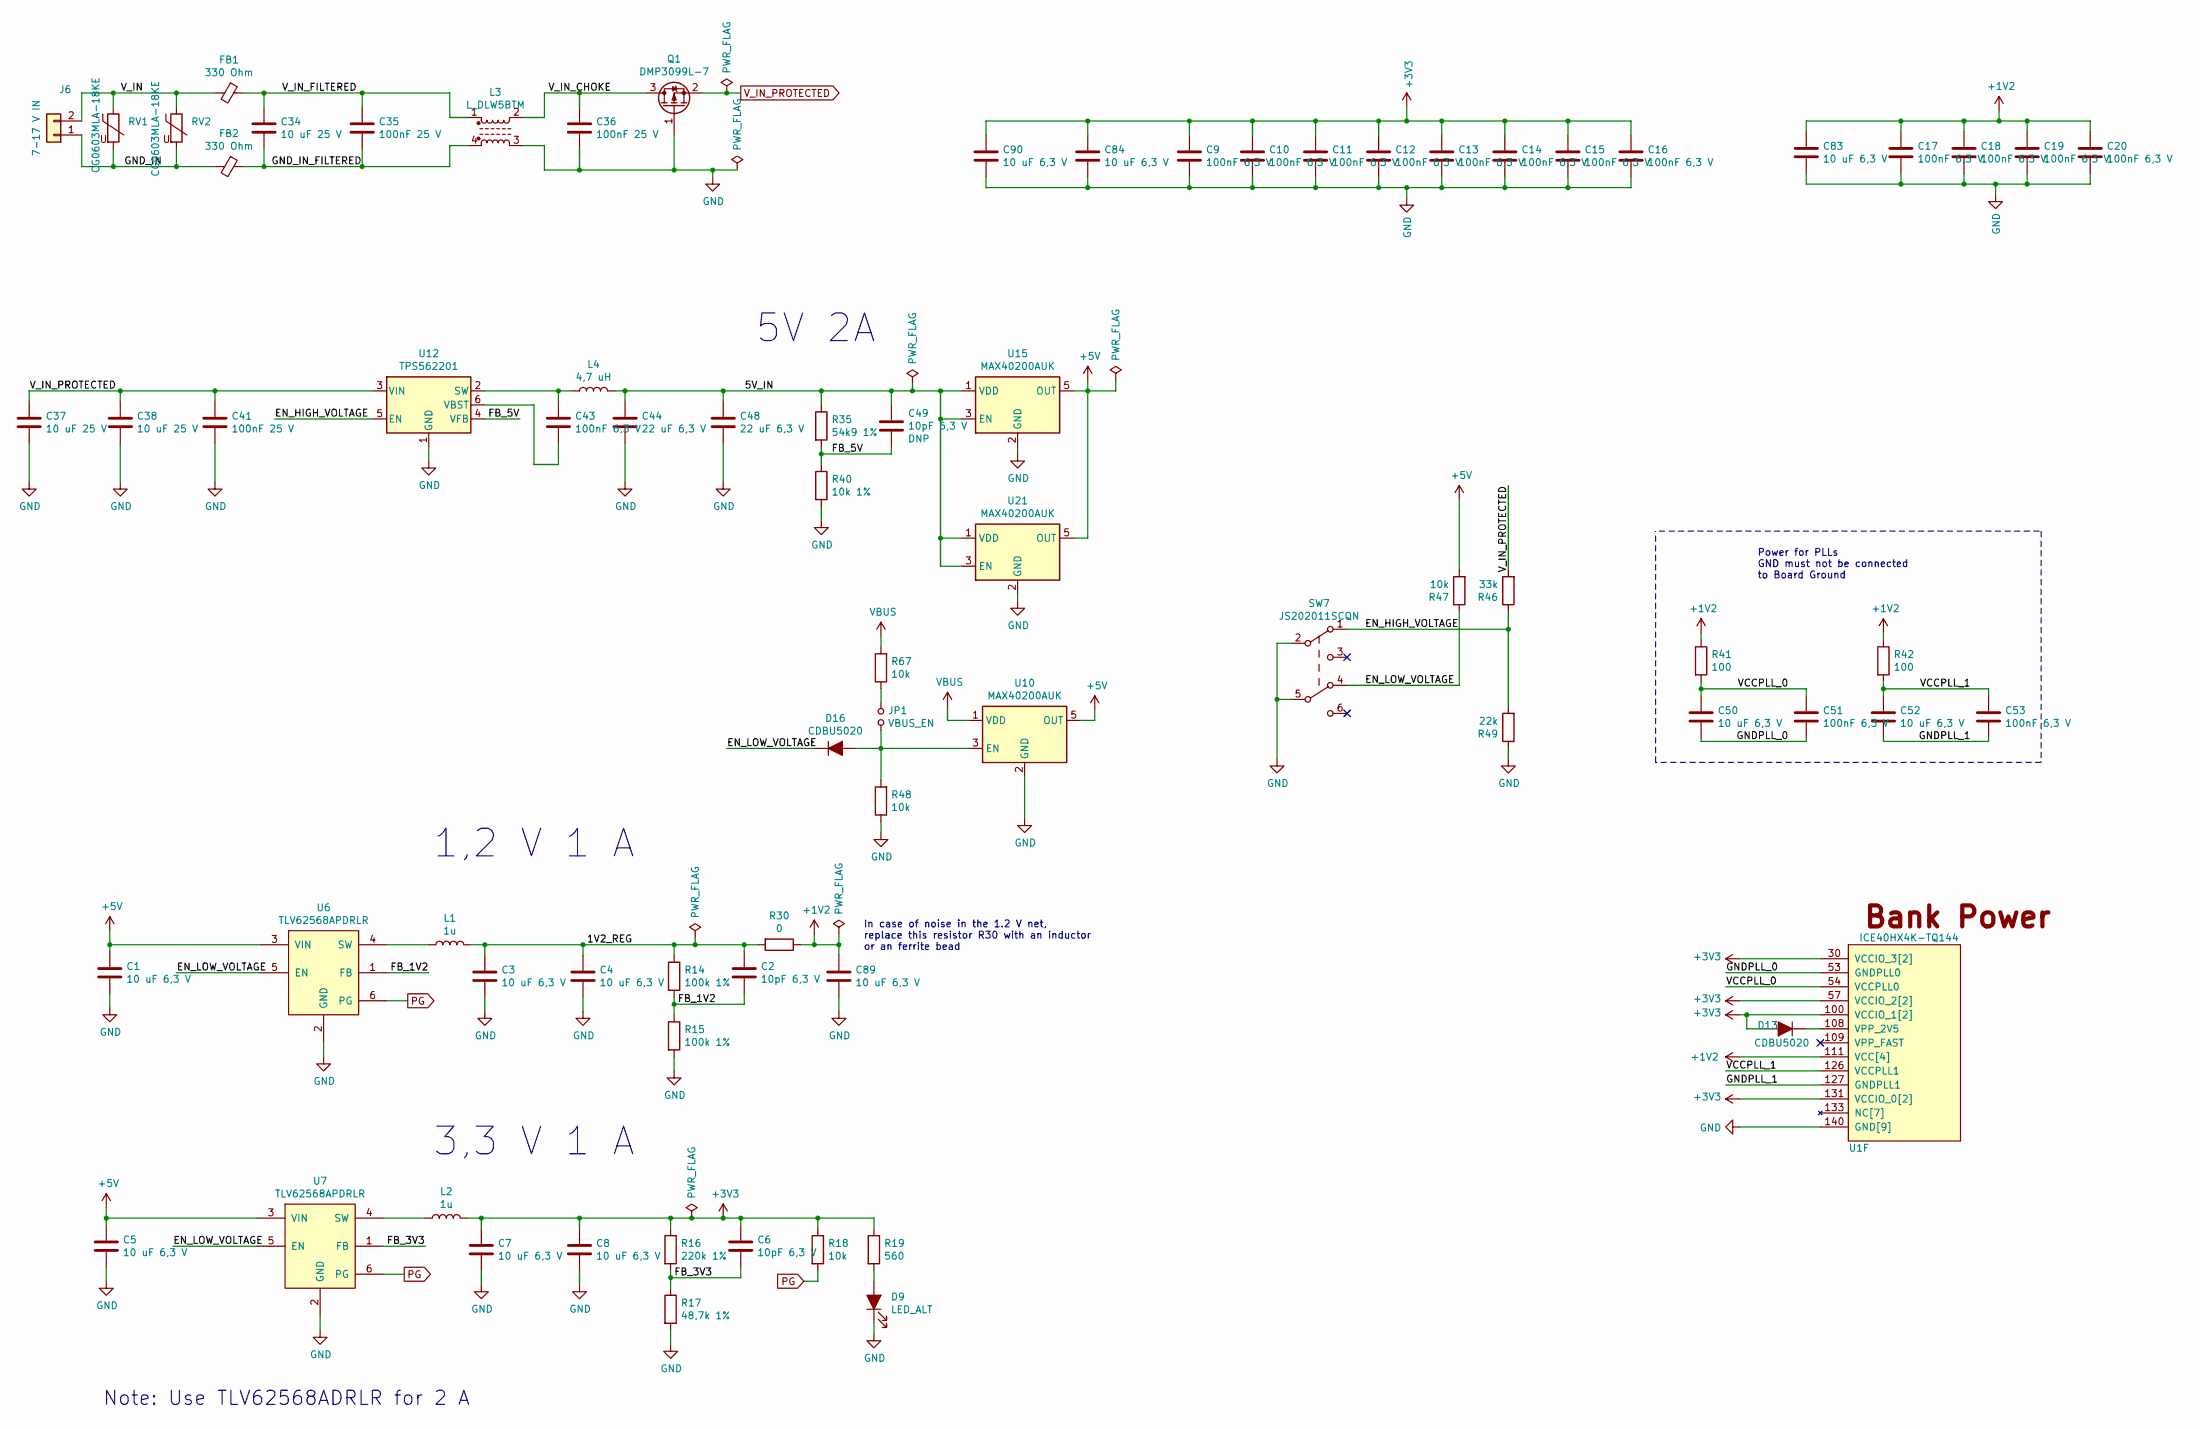
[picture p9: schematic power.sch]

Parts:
C1, C3, C4, C5, C7, C8, C50, C52, C83, C84, C89, C90: 10 uF 6,3 V; C_0603_1608Metric; Mfg Part Num CL10A106MQ8NNNC; Digikey 1276-1119-1-ND
C2, C6, C49: 10pF 6,3 V; C_0603_1608Metric; Mfg Part Num CL10C100JB8NNNC; Digikey 1276-1027-1-ND
C9, C10, C11, C12, C13, C14, C15, C16, C17, C18, C19, C20, C43, C51, C53: 100nF 6,3 V; C_0603_1608Metric; Mfg Part Num CL10B104KB8NNNC; Digikey 1276-1000-1-ND
C34, C37, C38: 10 uF 25 V; C_0805_2012Metric; Mfg Part Num CL21A106KAYNNNE; Digikey 1276-2891-1-ND
C35, C36, C41: 100nF 25 V; C_0603_1608Metric; Mfg Part Num CL10B104KB8NNNC; Digikey 1276-1000-1-ND
C44, C48: 22 uF 6,3 V; C_0603_1608Metric; Mfg Part Num GRM188R60J226MEA0D; Digikey 490-7611-1-ND
D9: LED_ALT; LED_0603_1608Metric
D13, D16: CDBU5020; D_0603_1608Metric; Mfg Part Num CDBU0520; Digikey 641-1332-1-ND
FB1, FB2: 330 Ohm; R_0805_2012Metric; Mfg Part Num MPZ2012S331AT000; Digikey 445-1569-1-ND
J6: 7-17 V IN; TerminalBlock_bornier-2_P5.08mm; Mfg Part Num TB007-508-02BE; Digikey 102-6203-ND
JP1: VBUS_EN; PinHeader_1x02_P2.54mm_Vertical
L1, L2: 1u; L_1008_2520Metric_2.5x2mm_footprint; Mfg Part Num MAMK2520T1R0M; Digikey 587-3225-1-ND
L3: L_DLW5BTM; L_Murata_DLW5BTM_5.00x5.00mm_footprint; Mfg Part Num DLW5BTM251SQ2L; Digikey 490-11111-1-ND
L4: 4,7 uH; L_Taiyo-Yuden_NR-50xx; Mfg Part Num NR5040T4R7N; Digikey 587-2373-1-ND
Q1: DMP3099L-7; SOT-23; Mfg Part Num DMP3099L-7; Digikey DMP3099L-7DICT-ND
R14, R15: 100k 1%; R_0603_1608Metric
R16: 220k 1%; R_0603_1608Metric
R17: 48,7k 1%; R_0603_1608Metric
R18, R47, R48, R67: 10k; R_0603_1608Metric
R19: 560; R_0603_1608Metric
R30: 0; R_0805_2012Metric
R35: 54k9 1%; R_0603_1608Metric
R40: 10k 1%; R_0603_1608Metric
R41, R42: 100; R_0603_1608Metric
R46: 33k; R_0603_1608Metric
R49: 22k; R_0603_1608Metric
RV1, RV2: CG0603MLA-18KE; R_0603_1608Metric; Mfg Part Num CG0603MLA-18KE; Digikey CG0603MLA-18KECT-ND
SW7: JS202011SCQN; SW_SLIDE_DPDT_Slide_CK_JS202011SCQN_W3mm_P2.5mm_footprint; Mfg Part Num JS202011SCQN; Digikey 401-2002-1-ND
U1: ICE40HX4K-TQ144; Mfg Part Num ICE40HX4K-TQ144; Digikey 220-1572-ND
U6, U7: TLV62568APDRLR; Texas_DRL_SOT-563_1.6x1.6mm_0.5mm-pitch_footprint; Mfg Part Num TLV62568APDRLR; Digikey 296-51691-1-ND
U10, U15, U21: MAX40200AUK; SOT-23-5; Mfg Part Num MAX40200AUK+T; Digikey MAX40200AUK+TCT-ND
U12: TPS562201; SOT-23-6; Mfg Part Num TPS562201DDCR; Digikey 296-44397-1-ND

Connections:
+1V2: C17.1, C18.1, C19.1, C20.1, C83.1, C89.1, R30.1, R41.1, R42.1, U1.27 (VCC), U1.40 (VCC), U1.92 (VCC), U1.111 (VCC[4])
+3V3: C6.1, C7.1, C8.1, C9.1, C10.1, C11.1, C12.1, C13.1, C14.1, C15.1, C16.1, C84.1, C90.1, D13.2 (A), L2.2, R16.1, R18.1, R19.1, U1.6 (VCCIO_3), U1.30 (VCCIO_3[2]), U1.46 (VCCIO_2), U1.57 (VCCIO_2[2]), U1.89 (VCCIO_1), U1.100 (VCCIO_1[2]), U1.123 (VCCIO_0), U1.131 (VCCIO_0[2]); also elsewhere on the board
+5V: C1.1, C5.1, R47.2, U6.3 (VIN), U7.3 (VIN), U10.5 (OUT), U15.5 (OUT), U21.5 (OUT); also elsewhere on the board
/power/1V2_REG: C2.1, C3.1, C4.1, L1.2, R14.1, R30.2
/power/5V_IN: C44.1, C48.1, C49.1, L4.2, R35.1, U15.1 (VDD), U15.3 (EN), U21.1 (VDD), U21.3 (EN)
/power/EN_HIGH_VOLTAGE: R46.1, R49.2, SW7.1 (A), U12.5 (EN)
/power/EN_LOW_VOLTAGE: D16.1 (K), R47.1, SW7.4 (A), U6.5 (EN), U7.5 (EN)
/power/FB_1V2: C2.2, R14.2, R15.1, U6.1 (FB)
/power/FB_3V3: C6.2, R16.2, R17.1, U7.1 (FB)
/power/FB_5V: C49.2, R35.2, R40.1, U12.4 (VFB)
/power/GNDPLL_0: C50.2, C51.2, U1.53 (GNDPLL0)
/power/GNDPLL_1: C52.2, C53.2, U1.127 (GNDPLL1)
/power/GND_IN: FB2.2, J6.1, RV1.2, RV2.2
/power/GND_IN_FILTERED: C34.2, C35.2, FB2.1, L3.4
/power/VCCPLL_0: C50.1, C51.1, R41.2, U1.54 (VCCPLL0)
/power/VCCPLL_1: C52.1, C53.1, R42.2, U1.126 (VCCPLL1)
/power/V_IN: FB1.2, J6.2, RV1.1, RV2.1
/power/V_IN_CHOKE: C36.1, L3.2, Q1.3 (D)
/power/V_IN_FILTERED: C34.1, C35.1, FB1.1, L3.1
CRESET_B: R18.2, U6.6 (PG), U7.6 (PG); also elsewhere on the board
GND: C1.2, C3.2, C4.2, C5.2, C7.2, C8.2, C9.2, C10.2, C11.2, C12.2, C13.2, C14.2, C15.2, C16.2, C17.2, C18.2, C19.2, C20.2, C36.2, C37.2, C38.2, C41.2, C44.2, C48.2, C83.2, C84.2, C89.2, C90.2, D9.1 (K), L3.3, Q1.1 (G), R15.2, R17.2, R40.2, R48.1, R49.1, SW7.2 (B), SW7.5 (B), U1.5 (GND), U1.13 (GND), U1.14 (GND), U1.59 (GND), U1.69 (GND), U1.86 (GND), U1.103 (GND), U1.132 (GND), U1.140 (GND[9]), U6.2 (GND), U7.2 (GND), U10.2 (GND), U12.1 (GND), U15.2 (GND), U21.2 (GND); also elsewhere on the board
unnamed: C43.1, L4.1, U12.2 (SW)
unnamed: C43.2, U12.6 (VBST)
unnamed: D9.2 (A), R19.2
unnamed: D13.1 (K), U1.108 (VPP_2V5)
unnamed: D16.2 (A), JP1.2, R48.2, U10.3 (EN)
unnamed: JP1.1, R67.1
unnamed: L1.1, U6.4 (SW)
unnamed: L2.1, U7.4 (SW)
unnamed: U1.35 (NC), U1.36 (NC), U1.50 (NC), U1.51 (NC), U1.58 (NC), U1.77 (NC), U1.133 (NC[7])
VBUS: R67.2, U10.1 (VDD); also elsewhere on the board
V_IN_PROTECTED: C37.1, C38.1, C41.1, Q1.2 (S), R46.2, U12.3 (VIN); also elsewhere on the board

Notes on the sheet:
3,3 V 1 A
Power for PLLs GND must not be connected to Board Ground
In case of noise in the 1.2 V net, replace this resistor R30 with an inductor or an ferrite bead
5V 2A
Note: Use TLV62568ADRLR for 2 A
1,2 V 1 A

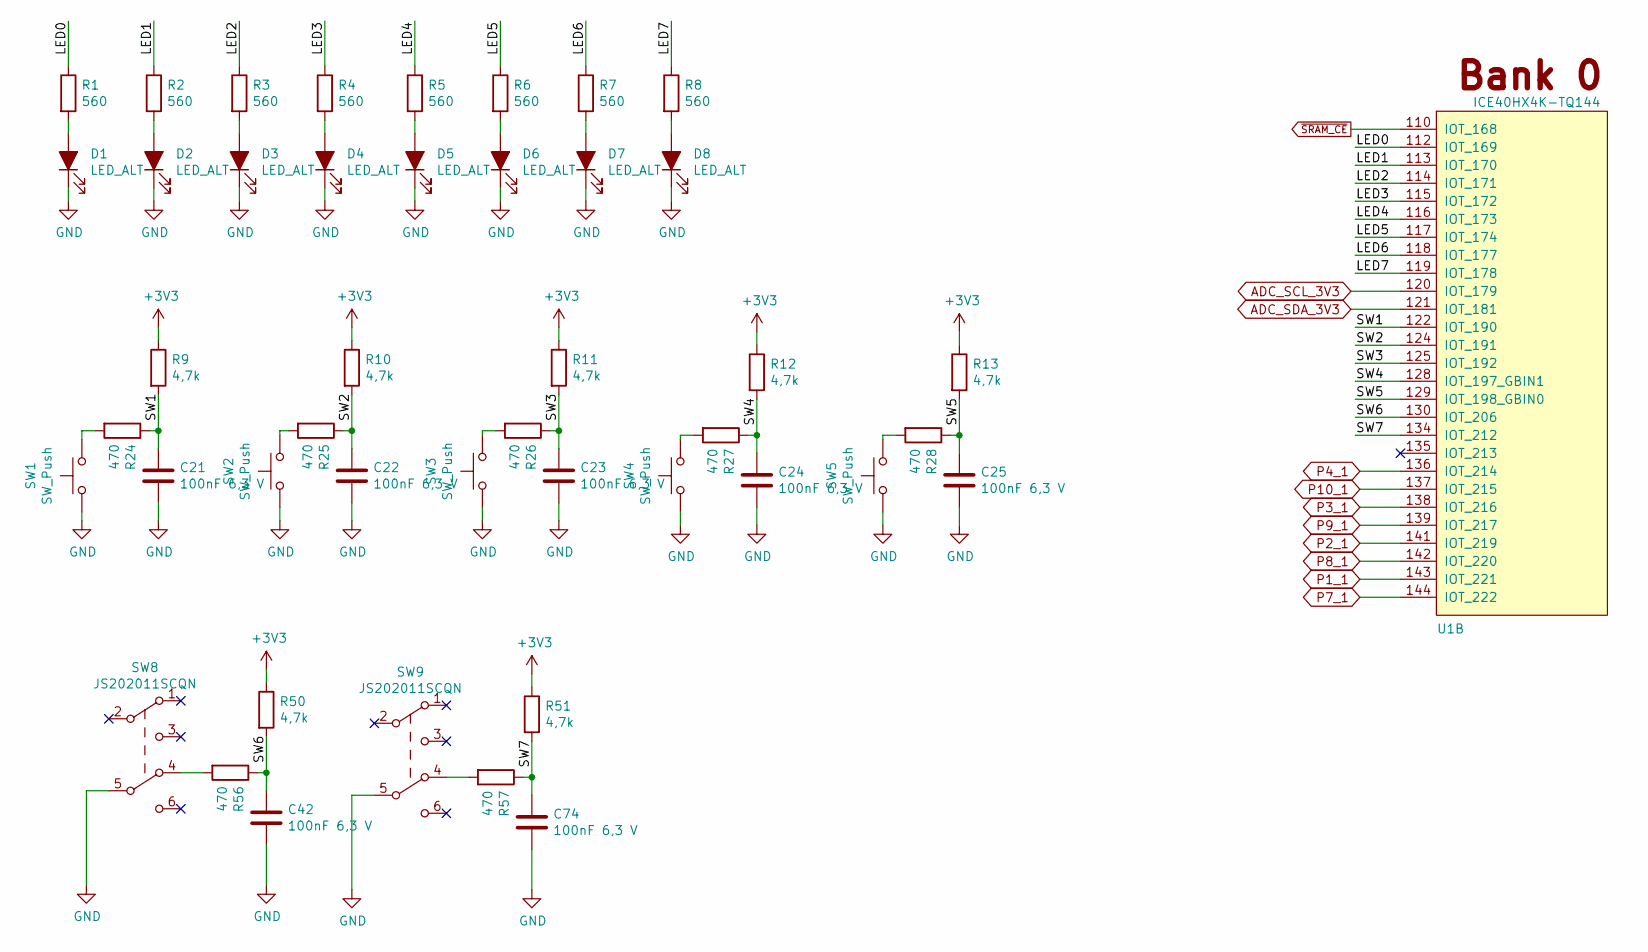
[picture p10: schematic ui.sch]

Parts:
C21, C22, C23, C24, C25, C42, C74: 100nF 6,3 V; C_0603_1608Metric; Mfg Part Num CL10B104KB8NNNC; Digikey 1276-1000-1-ND
D1, D2, D3, D4, D5, D6, D7, D8: LED_ALT; LED_0603_1608Metric
R1, R2, R3, R4, R5, R6, R7, R8: 560; R_0603_1608Metric
R9, R10, R11, R12, R13, R50, R51: 4,7k; R_0603_1608Metric
R24, R25, R26, R27, R28, R56, R57: 470; R_0603_1608Metric
SW1, SW2, SW3, SW4, SW5: SW_Push; SW_SPST_TL3305A; Mfg Part Num TL3305AF160QG; Digikey EG5350CT-ND
SW8, SW9: JS202011SCQN; SW_SLIDE_DPDT_Slide_CK_JS202011SCQN_W3mm_P2.5mm_footprint; Mfg Part Num JS202011SCQN; Digikey 401-2002-1-ND
U1: ICE40HX4K-TQ144; Mfg Part Num ICE40HX4K-TQ144; Digikey 220-1572-ND

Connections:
+3V3: R9.1, R10.1, R11.1, R12.1, R13.1, R50.1, R51.1; also elsewhere on the board
/User Interface/LED0: R1.1, U1.112 (IOT_169)
/User Interface/LED1: R2.1, U1.113 (IOT_170)
/User Interface/LED2: R3.1, U1.114 (IOT_171)
/User Interface/LED3: R4.1, U1.115 (IOT_172)
/User Interface/LED4: R5.1, U1.116 (IOT_173)
/User Interface/LED5: R6.1, U1.117 (IOT_174)
/User Interface/LED6: R7.1, U1.118 (IOT_177)
/User Interface/LED7: R8.1, U1.119 (IOT_178)
/User Interface/SW1: C21.1, R9.2, R24.1, U1.122 (IOT_190)
/User Interface/SW2: C22.1, R10.2, R25.1, U1.124 (IOT_191)
/User Interface/SW3: C23.1, R11.2, R26.1, U1.125 (IOT_192)
/User Interface/SW4: C24.1, R12.2, R27.1, U1.128 (IOT_197_GBIN1)
/User Interface/SW5: C25.1, R13.2, R28.1, U1.129 (IOT_198_GBIN0)
/User Interface/SW6: C42.1, R50.2, R56.1, U1.130 (IOT_206)
/User Interface/SW7: C74.1, R51.2, R57.1, U1.134 (IOT_212)
ADC_SCL_3V3: U1.120 (IOT_179); also elsewhere on the board
ADC_SDA_3V3: U1.121 (IOT_181); also elsewhere on the board
GND: C21.2, C22.2, C23.2, C24.2, C25.2, C42.2, C74.2, D1.1 (K), D2.1 (K), D3.1 (K), D4.1 (K), D5.1 (K), D6.1 (K), D7.1 (K), D8.1 (K), SW1.1, SW2.1, SW3.1, SW4.1, SW5.1, SW8.5 (B), SW9.5 (B); also elsewhere on the board
unnamed: D1.2 (A), R1.2
unnamed: D2.2 (A), R2.2
unnamed: D3.2 (A), R3.2
unnamed: D4.2 (A), R4.2
unnamed: D5.2 (A), R5.2
unnamed: D6.2 (A), R6.2
unnamed: D7.2 (A), R7.2
unnamed: D8.2 (A), R8.2
unnamed: R24.2, SW1.2
unnamed: R25.2, SW2.2
unnamed: R26.2, SW3.2
unnamed: R27.2, SW4.2
unnamed: R28.2, SW5.2
unnamed: R56.2, SW8.4 (A)
unnamed: R57.2, SW9.4 (A)
P1_1: U1.143 (IOT_221); also elsewhere on the board
P2_1: U1.141 (IOT_219); also elsewhere on the board
P3_1: U1.138 (IOT_216); also elsewhere on the board
P4_1: U1.136 (IOT_214); also elsewhere on the board
P7_1: U1.144 (IOT_222); also elsewhere on the board
P8_1: U1.142 (IOT_220); also elsewhere on the board
P9_1: U1.139 (IOT_217); also elsewhere on the board
P10_1: U1.137 (IOT_215); also elsewhere on the board
~SRAM_CE~: U1.110 (IOT_168); also elsewhere on the board

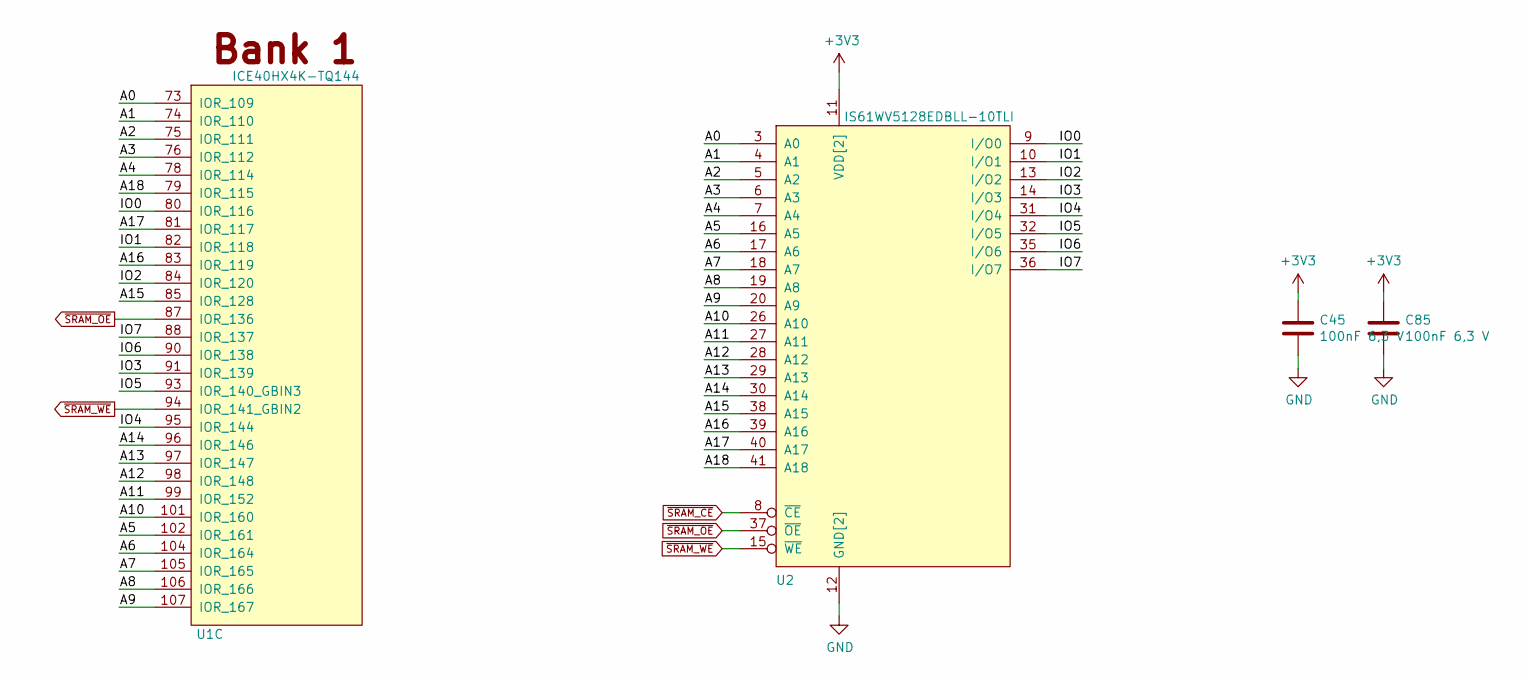
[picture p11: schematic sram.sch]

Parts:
C45, C85: 100nF 6,3 V; C_0603_1608Metric; Mfg Part Num CL10B104KB8NNNC; Digikey 1276-1000-1-ND
U1: ICE40HX4K-TQ144; Mfg Part Num ICE40HX4K-TQ144; Digikey 220-1572-ND
U2: IS61WV5128EDBLL-10TLI; TSOP-II-44_10.16x18.41mm_P0.8mm; Mfg Part Num IS61WV5128EDBLL-10TLI; Digikey 706-1147-ND

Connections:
+3V3: C45.1, C85.1, U2.11 (VDD[2]), U2.33 (VDD); also elsewhere on the board
/SRAM Memory/A0: U1.73 (IOR_109), U2.3 (A0)
/SRAM Memory/A1: U1.74 (IOR_110), U2.4 (A1)
/SRAM Memory/A2: U1.75 (IOR_111), U2.5 (A2)
/SRAM Memory/A3: U1.76 (IOR_112), U2.6 (A3)
/SRAM Memory/A4: U1.78 (IOR_114), U2.7 (A4)
/SRAM Memory/A5: U1.102 (IOR_161), U2.16 (A5)
/SRAM Memory/A6: U1.104 (IOR_164), U2.17 (A6)
/SRAM Memory/A7: U1.105 (IOR_165), U2.18 (A7)
/SRAM Memory/A8: U1.106 (IOR_166), U2.19 (A8)
/SRAM Memory/A9: U1.107 (IOR_167), U2.20 (A9)
/SRAM Memory/A10: U1.101 (IOR_160), U2.26 (A10)
/SRAM Memory/A11: U1.99 (IOR_152), U2.27 (A11)
/SRAM Memory/A12: U1.98 (IOR_148), U2.28 (A12)
/SRAM Memory/A13: U1.97 (IOR_147), U2.29 (A13)
/SRAM Memory/A14: U1.96 (IOR_146), U2.30 (A14)
/SRAM Memory/A15: U1.85 (IOR_128), U2.38 (A15)
/SRAM Memory/A16: U1.83 (IOR_119), U2.39 (A16)
/SRAM Memory/A17: U1.81 (IOR_117), U2.40 (A17)
/SRAM Memory/A18: U1.79 (IOR_115), U2.41 (A18)
/SRAM Memory/IO0: U1.80 (IOR_116), U2.9 (I/O0)
/SRAM Memory/IO1: U1.82 (IOR_118), U2.10 (I/O1)
/SRAM Memory/IO2: U1.84 (IOR_120), U2.13 (I/O2)
/SRAM Memory/IO3: U1.91 (IOR_139), U2.14 (I/O3)
/SRAM Memory/IO4: U1.95 (IOR_144), U2.31 (I/O4)
/SRAM Memory/IO5: U1.93 (IOR_140_GBIN3), U2.32 (I/O5)
/SRAM Memory/IO6: U1.90 (IOR_138), U2.35 (I/O6)
/SRAM Memory/IO7: U1.88 (IOR_137), U2.36 (I/O7)
GND: C45.2, C85.2, U2.12 (GND[2]), U2.34 (GND); also elsewhere on the board
~SRAM_CE~: U2.8 (~CE~); also elsewhere on the board
~SRAM_OE~: U1.87 (IOR_136), U2.37 (~OE~)
~SRAM_WE~: U1.94 (IOR_141_GBIN2), U2.15 (~WE~)

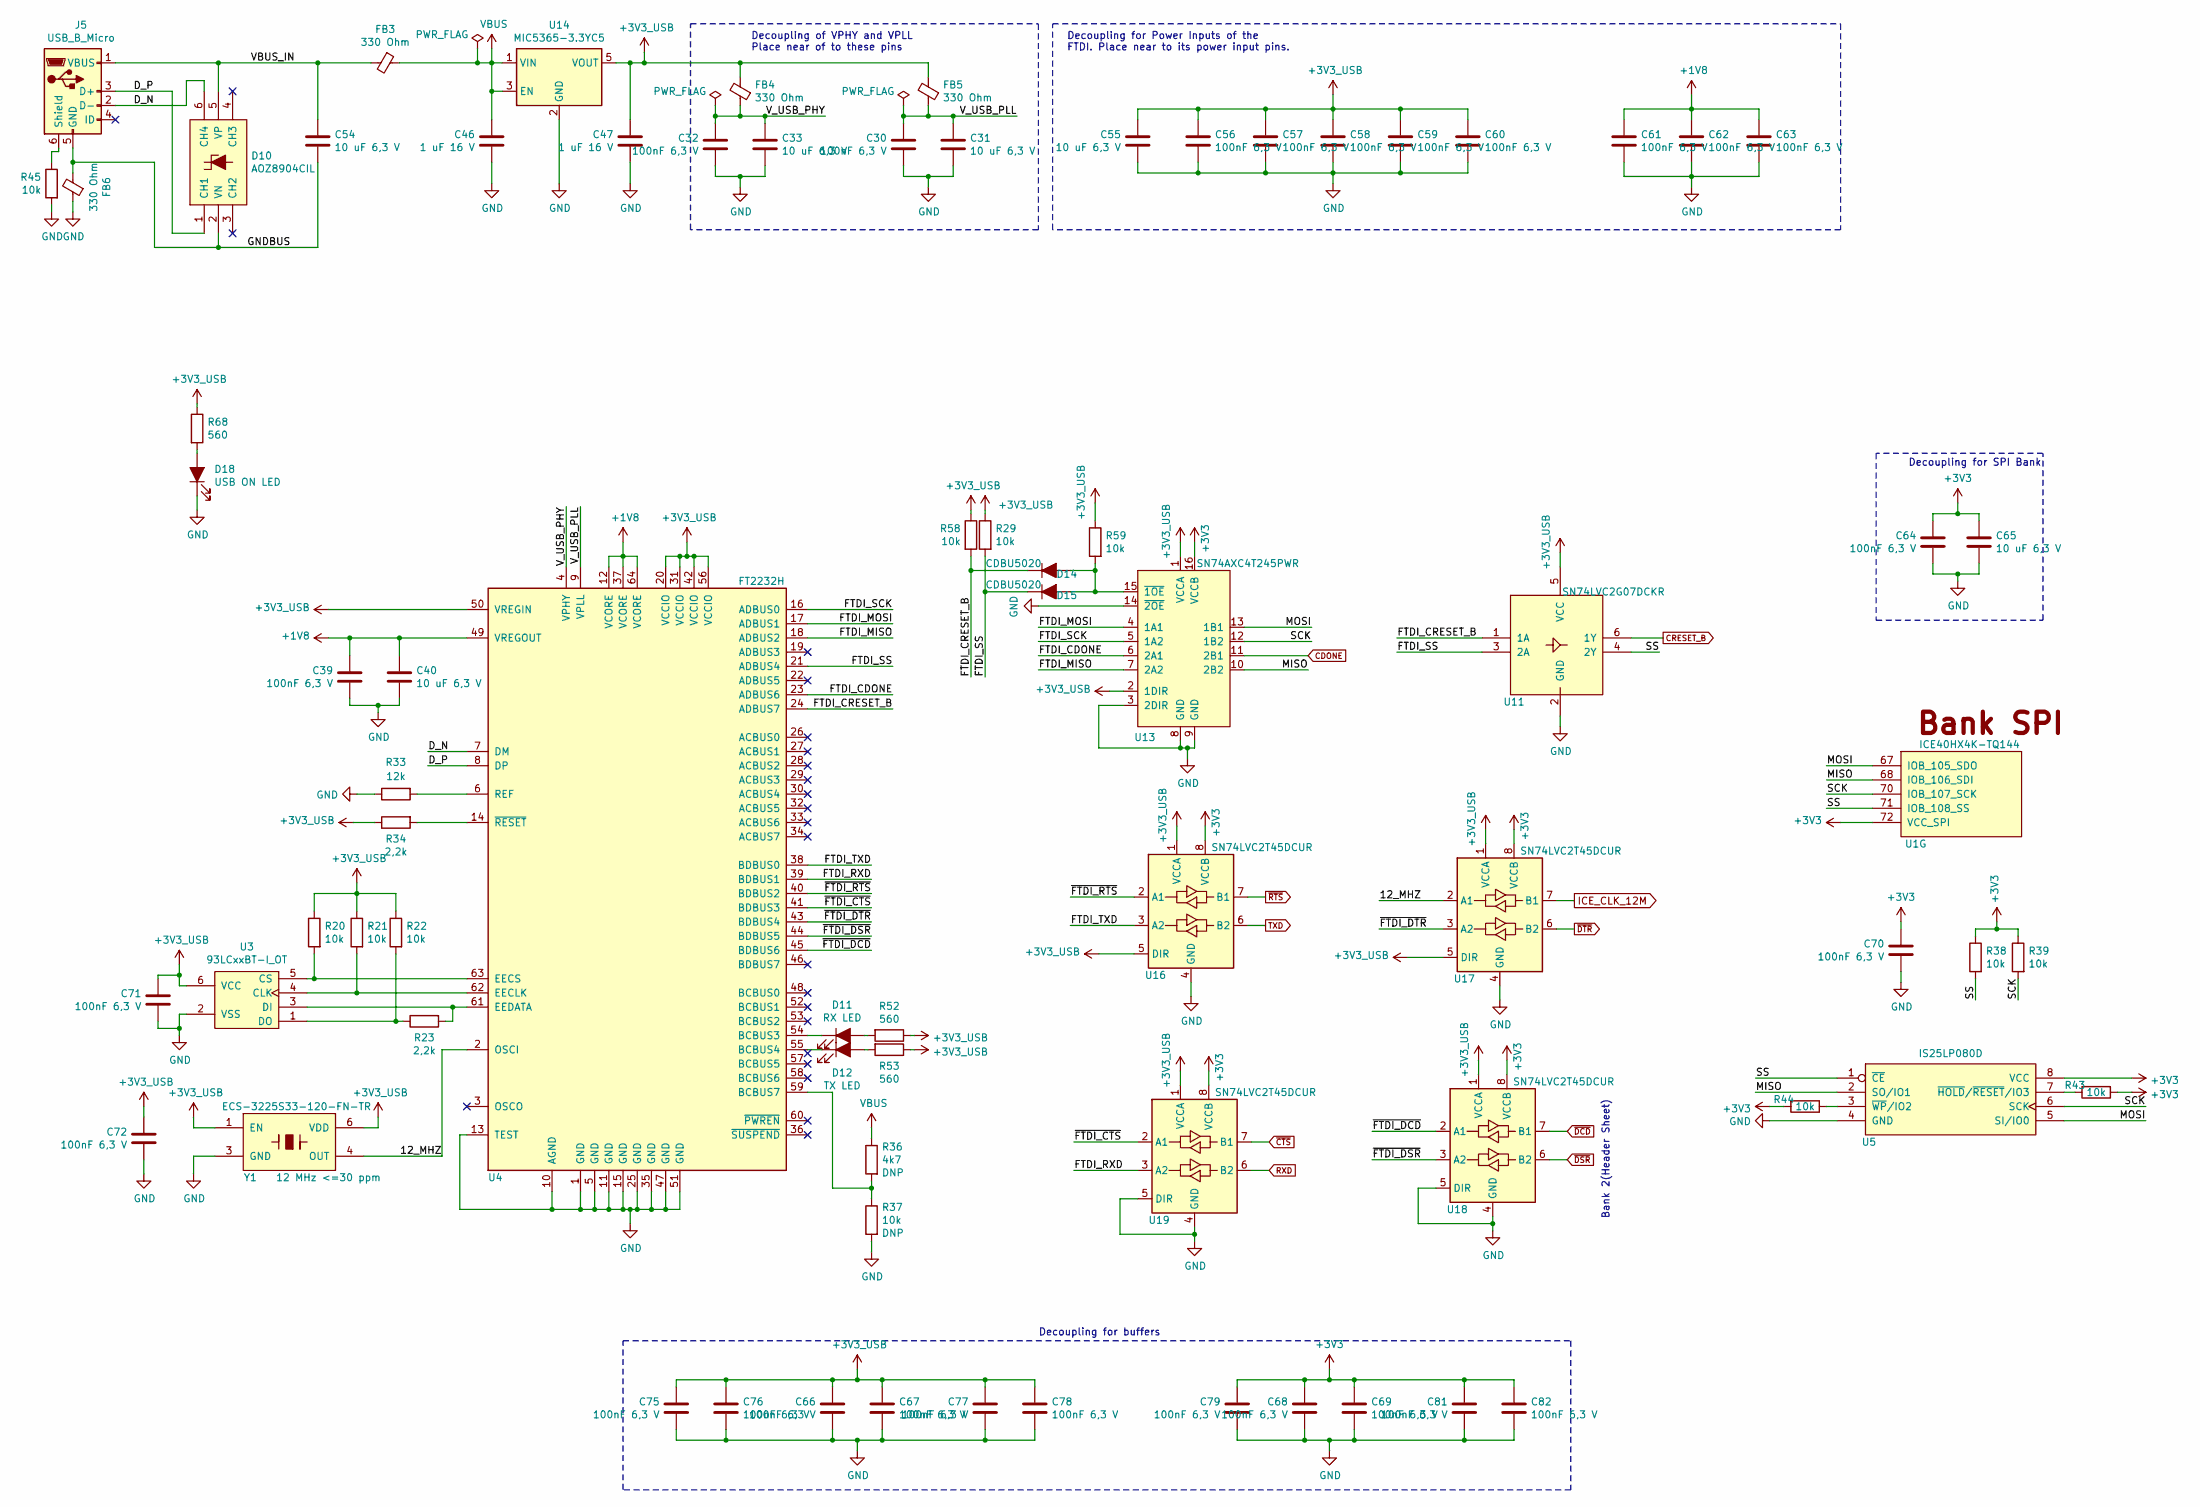
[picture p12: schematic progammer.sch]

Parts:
C30, C32, C39, C56, C57, C58, C59, C60, C61, C62, C63, C64, C66, C67, C68, C69, C70, C71, C72, C75, C76, C77, C78, C79, C81, C82: 100nF 6,3 V; C_0603_1608Metric; Mfg Part Num CL10B104KB8NNNC; Digikey 1276-1000-1-ND
C31, C33, C40, C54, C55, C65: 10 uF 6,3 V; C_0603_1608Metric; Mfg Part Num CL10A106MQ8NNNC; Digikey 1276-1119-1-ND
C46, C47: 1 uF 16 V; C_0603_1608Metric; Mfg Part Num CL10B105MO8NNWC; Digikey 1276-6524-1-ND
D10: AOZ8904CIL; SOT-23-6; Mfg Part Num AOZ8904CIL; Digikey 785-1755-1-ND
D11: RX LED; LED_0603_1608Metric
D12: TX LED; LED_0603_1608Metric
D14, D15: CDBU5020; D_0603_1608Metric; Mfg Part Num CDBU0520; Digikey 641-1332-1-ND
D18: USB ON LED; LED_0603_1608Metric
FB3, FB4, FB5, FB6: 330 Ohm; R_0805_2012Metric; Mfg Part Num MPZ2012S331AT000; Digikey 445-1569-1-ND
J5: USB_B_Micro; Amphenol_microUSB_B_footprint; Mfg Part Num 10118194-0001LF; Digikey 609-4618-1-ND
R20, R21, R22, R29, R37, R38, R39, R43, R44, R45, R58, R59: 10k; R_0603_1608Metric
R23, R34: 2,2k; R_0603_1608Metric
R33: 12k; R_0603_1608Metric
R36: 4k7; R_0603_1608Metric
R52, R53, R68: 560; R_0603_1608Metric
U1: ICE40HX4K-TQ144; Mfg Part Num ICE40HX4K-TQ144; Digikey 220-1572-ND
U3: 93LCxxBT-I_OT; SOT-23-6; Mfg Part Num 93LC56BT-I/OT; Digikey 93LC56BT-I/OTCT-ND
U4: FT2232H; LQFP-64_10x10mm_P0.5mm; Mfg Part Num FT2232HL-REEL; Digikey 768-1024-1-ND
U5: IS25LP080D; SO-8_3.9x4.9mm_P1.27mm; Mfg Part Num IS25LP080D-JNLE; Digikey 706-1580-ND
U11: SN74LVC2G07DCKR; SOT-363_SC-70-6; Mfg Part Num SN74LVC2G07DCKR; Digikey 296-13495-1-ND
U13: SN74AXC4T245PWR; TSSOP-16_4.4x5mm_P0.65mm; Mfg Part Num SN74AXC4T245PWR; Digikey 296-53472-1-ND
U14: MIC5365-3.3YC5; SOT-353_SC-70-5; Mfg Part Num MIC5365-3.3YC5-TR; Digikey 576-3193-1-ND
U16, U17, U18, U19: SN74LVC2T45DCUR; VSSOP-8_2.4x2.1mm_P0.5mm; Mfg Part Num SN74LVC2T45DCUR; Digikey 296-17014-1-ND
Y1: ECS-3225S33-120-FN-TR; Y_ECS-3225S_3.2x2.5mm_footprint; Mfg Part Num ECS-3225S33-120-FN-TR; Digikey XC2217CT-ND

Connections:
+1V8: C39.1, C40.1, C61.1, C62.1, C63.1, U4.12 (VCORE), U4.37 (VCORE), U4.49 (VREGOUT), U4.64 (VCORE)
+3V3: C64.1, C65.1, C68.1, C69.1, C70.1, C79.1, C81.1, C82.1, R38.1, R39.1, R43.2, R44.2, U1.72 (VCC_SPI), U5.8 (VCC), U13.16 (VCCB), U16.8 (VCCB), U17.8 (VCCB), U18.8 (VCCB), U19.8 (VCCB); also elsewhere on the board
+3V3_FTDI: C47.1, C55.1, C56.1, C57.1, C58.1, C59.1, C60.1, C66.1, C67.1, C71.1, C72.1, C75.1, C76.1, C77.1, C78.1, FB4.2, FB5.2, R20.1, R21.1, R22.1, R29.1, R34.1, R52.1, R53.1, R58.1, R59.1, R68.1, U3.6 (VCC), U4.20 (VCCIO), U4.31 (VCCIO), U4.42 (VCCIO), U4.50 (VREGIN), U4.56 (VCCIO), U11.5 (VCC), U13.1 (VCCA), U13.2 (1DIR), U14.5 (VOUT), U16.1 (VCCA), U16.5 (DIR), U17.1 (VCCA), U17.5 (DIR), U18.1 (VCCA), U19.1 (VCCA), Y1.1 (EN), Y1.6 (VDD)
/USB Programmer/12_MHZ: U4.2 (OSCI), U17.2 (A1), Y1.4 (OUT)
/USB Programmer/D_N: D10.6 (CH4), J5.2 (D-), U4.7 (DM)
/USB Programmer/D_P: D10.1 (CH1), J5.3 (D+), U4.8 (DP)
/USB Programmer/FTDI_CDONE: U4.23 (ADBUS6), U13.6 (2A1)
/USB Programmer/FTDI_CRESET_B: D14.1 (K), R58.2, U4.24 (ADBUS7), U11.1 (1A)
/USB Programmer/FTDI_MISO: U4.18 (ADBUS2), U13.7 (2A2)
/USB Programmer/FTDI_MOSI: U4.17 (ADBUS1), U13.4 (1A1)
/USB Programmer/FTDI_RXD: U4.39 (BDBUS1), U19.3 (A2)
/USB Programmer/FTDI_SCK: U4.16 (ADBUS0), U13.5 (1A2)
/USB Programmer/FTDI_SS: D15.1 (K), R29.2, U4.21 (ADBUS4), U11.3 (2A)
/USB Programmer/FTDI_TXD: U4.38 (BDBUS0), U16.3 (A2)
/USB Programmer/GNDBUS: C54.2, D10.2 (VN), FB6.2, J5.5 (GND)
/USB Programmer/MISO: U1.68 (IOB_106_SDI), U5.2 (SO/IO1), U13.10 (2B2)
/USB Programmer/MOSI: U1.67 (IOB_105_SDO), U5.5 (SI/IO0), U13.13 (1B1)
/USB Programmer/SCK: R39.2, U1.70 (IOB_107_SCK), U5.6 (SCK), U13.12 (1B2)
/USB Programmer/SS: R38.2, U1.71 (IOB_108_SS), U5.1 (~CE~), U11.4 (2Y)
/USB Programmer/VBUS_IN: C54.1, D10.5 (VP), FB3.2, J5.1 (VBUS)
/USB Programmer/V_USB_PHY: C32.1, C33.1, FB4.1, U4.4 (VPHY)
/USB Programmer/V_USB_PLL: C30.1, C31.1, FB5.1, U4.9 (VPLL)
/USB Programmer/~FTDI_CTS~: U4.41 (BDBUS3), U19.2 (A1)
/USB Programmer/~FTDI_DCD~: U4.45 (BDBUS6), U18.2 (A1)
/USB Programmer/~FTDI_DSR~: U4.44 (BDBUS5), U18.3 (A2)
/USB Programmer/~FTDI_DTR~: U4.43 (BDBUS4), U17.3 (A2)
/USB Programmer/~FTDI_RTS~: U4.40 (BDBUS2), U16.2 (A1)
CDONE: U13.11 (2B1); also elsewhere on the board
CRESET_B: U11.6 (1Y); also elsewhere on the board
GND: C30.2, C31.2, C32.2, C33.2, C39.2, C40.2, C46.2, C47.2, C55.2, C56.2, C57.2, C58.2, C59.2, C60.2, C61.2, C62.2, C63.2, C64.2, C65.2, C66.2, C67.2, C68.2, C69.2, C70.2, C71.2, C72.2, C75.2, C76.2, C77.2, C78.2, C79.2, C81.2, C82.2, D18.1 (K), FB6.1, R33.1, R37.2, R45.2, U3.2 (VSS), U4.1 (GND), U4.5 (GND), U4.10 (AGND), U4.11 (GND), U4.13 (TEST), U4.15 (GND), U4.25 (GND), U4.35 (GND), U4.47 (GND), U4.51 (GND), U5.4 (GND), U11.2 (GND), U13.3 (2DIR), U13.8 (GND), U13.9 (GND), U13.14 (~2OE~), U14.2 (GND), U16.4 (GND), U17.4 (GND), U18.4 (GND), U18.5 (DIR), U19.4 (GND), U19.5 (DIR), Y1.3 (GND); also elsewhere on the board
ICE_CLK_12M: U17.7 (B1); also elsewhere on the board
unnamed: D11.1 (K), U4.54 (BCBUS3)
unnamed: D11.2 (A), R52.2
unnamed: D12.1 (K), U4.55 (BCBUS4)
unnamed: D12.2 (A), R53.2
unnamed: D14.2 (A), D15.2 (A), R59.2, U13.15 (~1OE~)
unnamed: D18.2 (A), R68.2
unnamed: J5.6 (Shield), R45.1
unnamed: R20.2, U3.5 (CS), U4.63 (EECS)
unnamed: R21.2, U3.4 (CLK), U4.62 (EECLK)
unnamed: R22.2, R23.1, U3.1 (DO)
unnamed: R23.2, U3.3 (DI), U4.61 (EEDATA)
unnamed: R33.2, U4.6 (REF)
unnamed: R34.2, U4.14 (~RESET)
unnamed: R36.2, R37.1, U4.59 (BCBUS7)
unnamed: R43.1, U5.7 (~HOLD~/~RESET~/IO3)
unnamed: R44.1, U5.3 (~WP~/IO2)
RXD: U19.6 (B2); also elsewhere on the board
TXD: U16.6 (B2); also elsewhere on the board
VBUS: C46.1, FB3.1, R36.1, U14.1 (VIN), U14.3 (EN); also elsewhere on the board
~CTS~: U19.7 (B1); also elsewhere on the board
~DCD~: U18.7 (B1); also elsewhere on the board
~DSR~: U18.6 (B2); also elsewhere on the board
~DTR~: U17.6 (B2); also elsewhere on the board
~RTS~: U16.7 (B1); also elsewhere on the board

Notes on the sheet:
Decoupling of VPHY and VPLL Place near of to these pins
Bank 2(Header Sheet)
Decoupling for Power Inputs of the FTDI. Place near to its power input pins.
Decoupling for buffers
Decoupling for SPI Bank

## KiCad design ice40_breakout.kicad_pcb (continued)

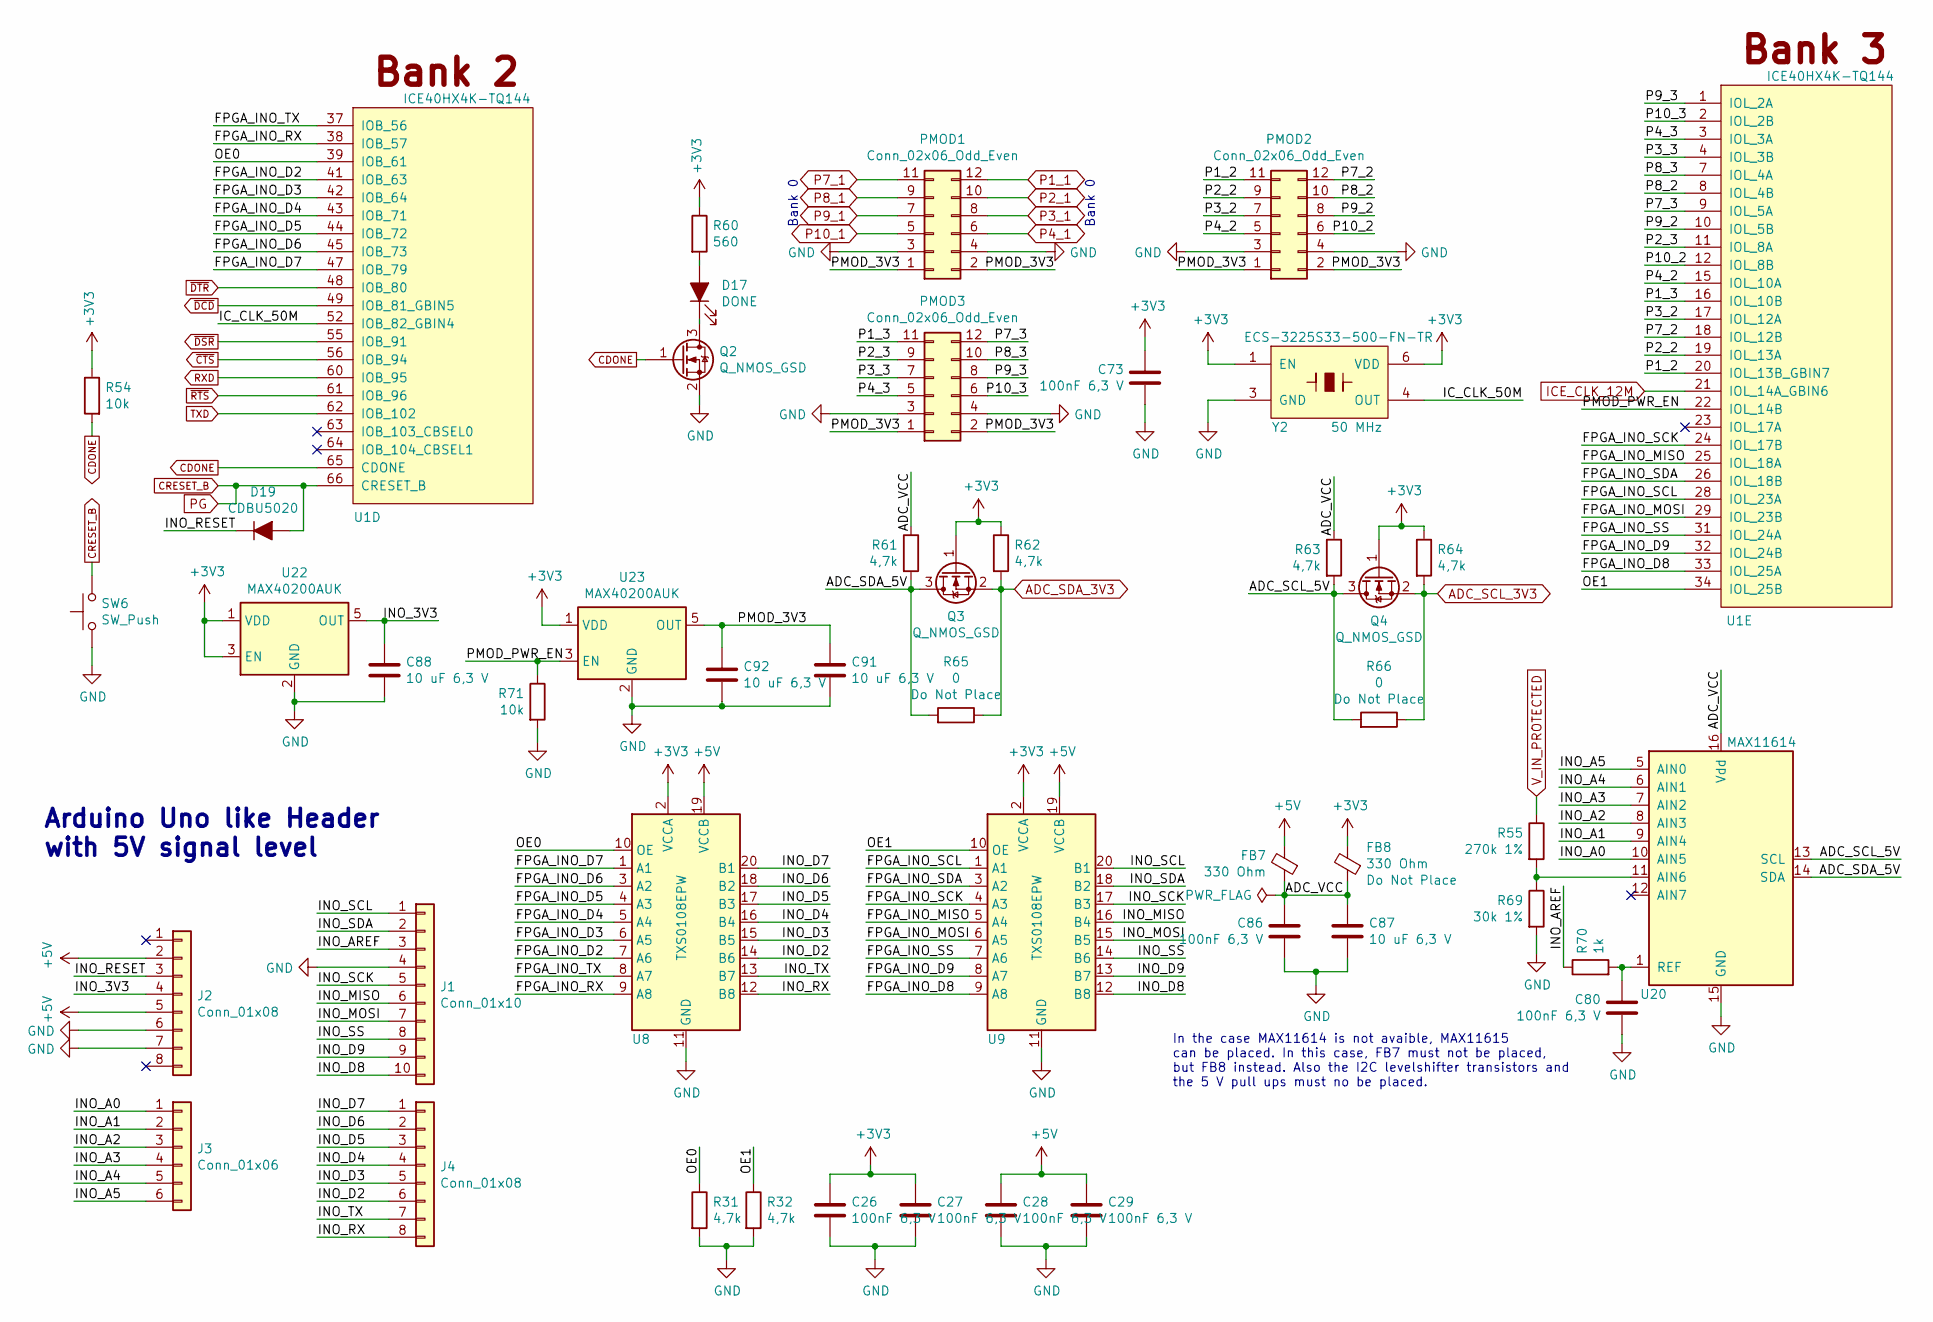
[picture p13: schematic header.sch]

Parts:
C26, C27, C28, C29, C73, C80, C86: 100nF 6,3 V; C_0603_1608Metric; Mfg Part Num CL10B104KB8NNNC; Digikey 1276-1000-1-ND
C87, C88, C91, C92: 10 uF 6,3 V; C_0603_1608Metric; Mfg Part Num CL10A106MQ8NNNC; Digikey 1276-1119-1-ND
D17: DONE; LED_0603_1608Metric
D19: CDBU5020; D_0603_1608Metric; Mfg Part Num CDBU0520; Digikey 641-1332-1-ND
FB7, FB8: 330 Ohm; R_0805_2012Metric; Mfg Part Num MPZ2012S331AT000; Digikey 445-1569-1-ND
J1: Conn_01x10; PinSocket_1x10_P2.54mm_Vertical
J2, J4: Conn_01x08; PinSocket_1x08_P2.54mm_Vertical
J3: Conn_01x06; PinSocket_1x06_P2.54mm_Vertical
PMOD1, PMOD2, PMOD3: Conn_02x06_Odd_Even; PinSocket_2x06_P2.54mm_Horizontal
Q2, Q3, Q4: Q_NMOS_GSD; SOT-23; Mfg Part Num DMN65D8L-7; Digikey DMN65D8L-7DICT-ND
R31, R32, R61, R62, R63, R64: 4,7k; R_0603_1608Metric
R54, R71: 10k; R_0603_1608Metric
R55: 270k 1%; R_0603_1608Metric
R60: 560; R_0603_1608Metric
R65, R66: 0; R_0603_1608Metric
R69: 30k 1%; R_0603_1608Metric
R70: 1k; R_0603_1608Metric
SW6: SW_Push; SW_SPST_TL3305A; Mfg Part Num TL3305AF160QG; Digikey EG5350CT-ND
U1: ICE40HX4K-TQ144; Mfg Part Num ICE40HX4K-TQ144; Digikey 220-1572-ND
U8, U9: TXS0108EPW; TSSOP-20_4.4x6.5mm_P0.65mm; Mfg Part Num TXS0108EPWR; Digikey 296-23011-1-ND
U20: MAX11614; QSOP-16_3.9x4.9mm_P0.635mm; Mfg Part Num MAX11614EEE+; Digikey MAX11614EEE+-ND
U22, U23: MAX40200AUK; SOT-23-5; Mfg Part Num MAX40200AUK+T; Digikey MAX40200AUK+TCT-ND
Y2: ECS-3225S33-500-FN-TR; Y_ECS-3225S_3.2x2.5mm_footprint; Mfg Part Num ECS-3225S33-500-FN-TR; Digikey XC2226CT-ND

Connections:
+3V3: C26.1, C27.1, C73.1, FB8.2, Q3.1 (G), Q4.1 (G), R54.1, R60.1, R62.1, R64.1, U8.2 (VCCA), U9.2 (VCCA), U22.1 (VDD), U22.3 (EN), U23.1 (VDD), Y2.1 (EN), Y2.6 (VDD); also elsewhere on the board
+5V: C28.1, C29.1, FB7.2, J2.2, J2.5, U8.19 (VCCB), U9.19 (VCCB); also elsewhere on the board
/Header/ADC_SCL_5V: Q4.3 (D), R63.2, R66.2, U20.13 (SCL)
/Header/ADC_SDA_5V: Q3.3 (D), R61.2, R65.2, U20.14 (SDA)
/Header/ADC_VCC: C86.1, C87.1, FB7.1, FB8.1, R61.1, R63.1, U20.16 (Vdd)
/Header/FPGA_INO_D2: U1.41 (IOB_63), U8.7 (A6)
/Header/FPGA_INO_D3: U1.42 (IOB_64), U8.6 (A5)
/Header/FPGA_INO_D4: U1.43 (IOB_71), U8.5 (A4)
/Header/FPGA_INO_D5: U1.44 (IOB_72), U8.4 (A3)
/Header/FPGA_INO_D6: U1.45 (IOB_73), U8.3 (A2)
/Header/FPGA_INO_D7: U1.47 (IOB_79), U8.1 (A1)
/Header/FPGA_INO_D8: U1.33 (IOL_25A), U9.9 (A8)
/Header/FPGA_INO_D9: U1.32 (IOL_24B), U9.8 (A7)
/Header/FPGA_INO_MISO: U1.25 (IOL_18A), U9.5 (A4)
/Header/FPGA_INO_MOSI: U1.29 (IOL_23B), U9.6 (A5)
/Header/FPGA_INO_RX: U1.38 (IOB_57), U8.9 (A8)
/Header/FPGA_INO_SCK: U1.24 (IOL_17B), U9.4 (A3)
/Header/FPGA_INO_SCL: U1.28 (IOL_23A), U9.1 (A1)
/Header/FPGA_INO_SDA: U1.26 (IOL_18B), U9.3 (A2)
/Header/FPGA_INO_SS: U1.31 (IOL_24A), U9.7 (A6)
/Header/FPGA_INO_TX: U1.37 (IOB_56), U8.8 (A7)
/Header/IC_CLK_50M: U1.52 (IOB_82_GBIN4), Y2.4 (OUT)
/Header/INO_3V3: C88.1, J2.4, U22.5 (OUT)
/Header/INO_A0: J3.1, U20.10 (AIN5)
/Header/INO_A1: J3.2, U20.9 (AIN4)
/Header/INO_A2: J3.3, U20.8 (AIN3)
/Header/INO_A3: J3.4, U20.7 (AIN2)
/Header/INO_A4: J3.5, U20.6 (AIN1)
/Header/INO_A5: J3.6, U20.5 (AIN0)
/Header/INO_AREF: J1.3, R70.1
/Header/INO_D2: J4.6, U8.14 (B6)
/Header/INO_D3: J4.5, U8.15 (B5)
/Header/INO_D4: J4.4, U8.16 (B4)
/Header/INO_D5: J4.3, U8.17 (B3)
/Header/INO_D6: J4.2, U8.18 (B2)
/Header/INO_D7: J4.1, U8.20 (B1)
/Header/INO_D8: J1.10, U9.12 (B8)
/Header/INO_D9: J1.9, U9.13 (B7)
/Header/INO_MISO: J1.6, U9.16 (B4)
/Header/INO_MOSI: J1.7, U9.15 (B5)
/Header/INO_RESET: D19.1 (K), J2.3
/Header/INO_RX: J4.8, U8.12 (B8)
/Header/INO_SCK: J1.5, U9.17 (B3)
/Header/INO_SCL: J1.1, U9.20 (B1)
/Header/INO_SDA: J1.2, U9.18 (B2)
/Header/INO_SS: J1.8, U9.14 (B6)
/Header/INO_TX: J4.7, U8.13 (B7)
/Header/OE0: R31.1, U1.39 (IOB_61), U8.10 (OE)
/Header/OE1: R32.1, U1.34 (IOL_25B), U9.10 (OE)
/Header/P1_2: PMOD2.11, U1.20 (IOL_13B_GBIN7)
/Header/P1_3: PMOD3.11, U1.16 (IOL_10B)
/Header/P2_2: PMOD2.9, U1.19 (IOL_13A)
/Header/P2_3: PMOD3.9, U1.11 (IOL_8A)
/Header/P3_2: PMOD2.7, U1.17 (IOL_12A)
/Header/P3_3: PMOD3.7, U1.4 (IOL_3B)
/Header/P4_2: PMOD2.5, U1.15 (IOL_10A)
/Header/P4_3: PMOD3.5, U1.3 (IOL_3A)
/Header/P7_2: PMOD2.12, U1.18 (IOL_12B)
/Header/P7_3: PMOD3.12, U1.9 (IOL_5A)
/Header/P8_2: PMOD2.10, U1.8 (IOL_4B)
/Header/P8_3: PMOD3.10, U1.7 (IOL_4A)
/Header/P9_2: PMOD2.8, U1.10 (IOL_5B)
/Header/P9_3: PMOD3.8, U1.1 (IOL_2A)
/Header/P10_2: PMOD2.6, U1.12 (IOL_8B)
/Header/P10_3: PMOD3.6, U1.2 (IOL_2B)
/Header/PMOD_3V3: C91.1, C92.1, PMOD1.1, PMOD1.2, PMOD2.1, PMOD2.2, PMOD3.1, PMOD3.2, U23.5 (OUT)
/Header/PMOD_PWR_EN: R71.1, U1.22 (IOL_14B), U23.3 (EN)
ADC_SCL_3V3: Q4.2 (S), R64.2, R66.1; also elsewhere on the board
ADC_SDA_3V3: Q3.2 (S), R62.2, R65.1; also elsewhere on the board
CDONE: Q2.1 (G), R54.2, U1.65 (CDONE); also elsewhere on the board
CRESET_B: D19.2 (A), SW6.2, U1.66 (CRESET_B); also elsewhere on the board
GND: C26.2, C27.2, C28.2, C29.2, C73.2, C80.2, C86.2, C87.2, C88.2, C91.2, C92.2, J1.4, J2.6, J2.7, PMOD1.3, PMOD1.4, PMOD2.3, PMOD2.4, PMOD3.3, PMOD3.4, Q2.2 (S), R31.2, R32.2, R69.2, R71.2, SW6.1, U8.11 (GND), U9.11 (GND), U20.15 (GND), U22.2 (GND), U23.2 (GND), Y2.3 (GND); also elsewhere on the board
ICE_CLK_12M: U1.21 (IOL_14A_GBIN6); also elsewhere on the board
unnamed: C80.1, R70.2, U20.1 (REF)
unnamed: D17.1 (K), Q2.3 (D)
unnamed: D17.2 (A), R60.2
unnamed: R55.2, R69.1, U20.11 (AIN6)
P1_1: PMOD1.12; also elsewhere on the board
P2_1: PMOD1.10; also elsewhere on the board
P3_1: PMOD1.8; also elsewhere on the board
P4_1: PMOD1.6; also elsewhere on the board
P7_1: PMOD1.11; also elsewhere on the board
P8_1: PMOD1.9; also elsewhere on the board
P9_1: PMOD1.7; also elsewhere on the board
P10_1: PMOD1.5; also elsewhere on the board
RXD: U1.60 (IOB_95); also elsewhere on the board
TXD: U1.62 (IOB_102); also elsewhere on the board
V_IN_PROTECTED: R55.1; also elsewhere on the board
~CTS~: U1.56 (IOB_94); also elsewhere on the board
~DCD~: U1.49 (IOB_81_GBIN5); also elsewhere on the board
~DSR~: U1.55 (IOB_91); also elsewhere on the board
~DTR~: U1.48 (IOB_80); also elsewhere on the board
~RTS~: U1.61 (IOB_96); also elsewhere on the board

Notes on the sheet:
Arduino Uno like Header with 5V signal level
Bank 0
In the case MAX11614 is not avaible, MAX11615 can be placed. In this case, FB7 must not be placed, but FB8 instead. Also the I2C levelshifter transistors and the 5 V pull ups must no be placed.

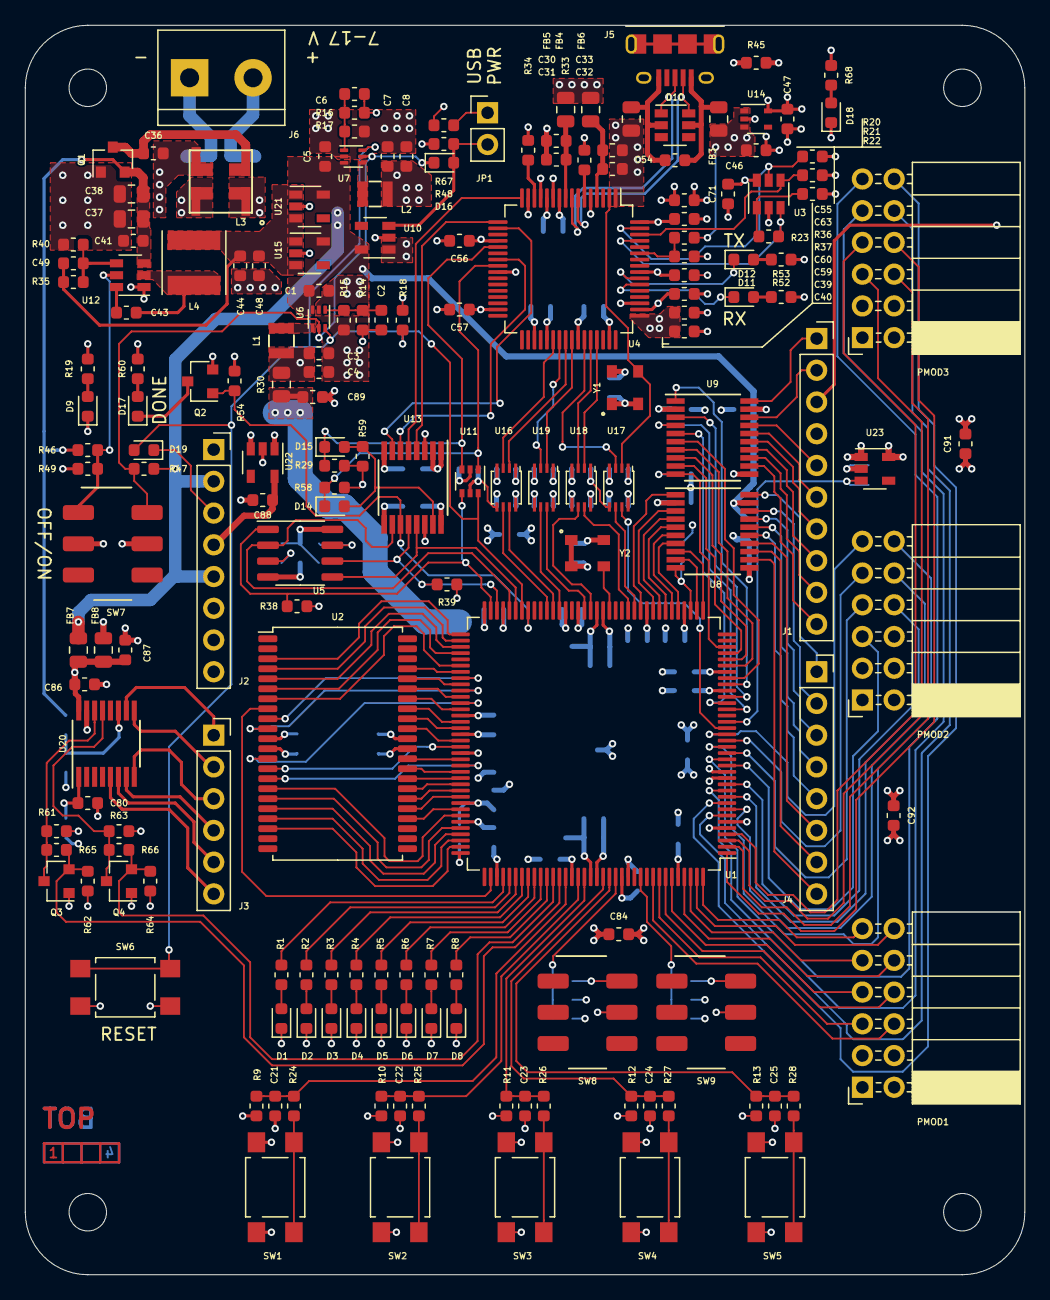
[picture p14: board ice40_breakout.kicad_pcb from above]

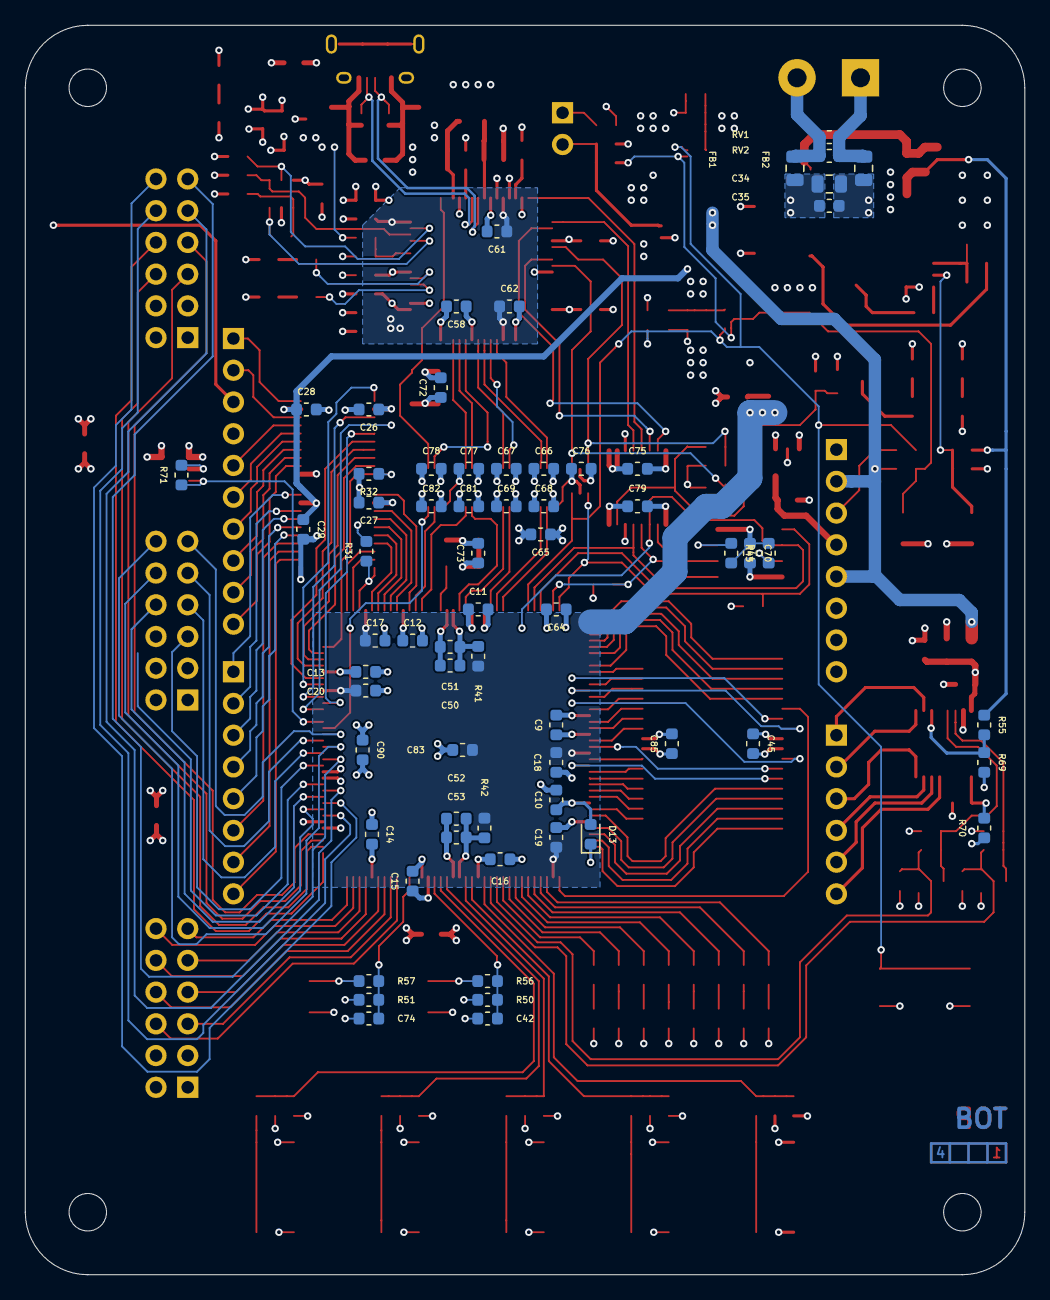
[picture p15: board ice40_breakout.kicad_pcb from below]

Board: 4 copper layers, 80.0 x 100.0 mm, 248 parts (66 on the bottom side), 222 nets.

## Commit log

2019-04-07 Made a first symbol for the ice40hx4k with TQFP144 footprint.
    Also added a FTDI chip for programming, two flashes and a SRAM to the schematic
    [ice40_breakout.kicad_pcb, ice40_breakout.sch, power.sch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]
2019-04-07 Made a overview on the toplevel schematic and added the SRAM subschematic.
    [header.sch, ice40_breakout.sch, power.sch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]
2019-04-20 Footprint and 3d model for usb-micro
2019-04-20 Footprint for Taiyo Yuden 1008
2019-04-20 Foorptint and 3d model for tl3305a buttons
2019-04-20 Add symbol for aoz8904cil TVS Diode
2019-04-20 sram, ui, power, flash and header
    SRAM: mostly done. Changed the choosen IC to a faster one in a differenc housing.
    POWER: added some step down converter for 3.3 V and 1.2 V. The 1.2 V is oversized and could be changed to a smaller one
    Programmer: added flash.
    HEADER: Added Arduino Uno like headers with 5 V signal level. Analog is not connected now, will get an I2C ADC in future. Also added 3 digilent pmod styled connector with 3.3 V signal level.
    UI: added 5 buttons and 8 LEDs. There is some space left over, maybe double the LED count in future.
    [header.sch, ice40_breakout.kicad_pcb, ice40_breakout.sch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]
2019-04-21 Symbol, Footprint and 3d model for ECS-3225S crystal oscillator
2019-04-21 Progress on FTDI - added Oscillator and 1.8 V supply
    [ice40_breakout.kicad_pcb, ice40_breakout.sch, progammer.sch]
2019-04-22 Continued on Programmer, moved the header signals around the package to free some space for a fully featured UART/RS232(TTL)
    [header.sch, ice40_breakout.kicad_pcb, progammer.sch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]
2019-05-05 Added switches, added 5 V rail and 17 V input(with filtering). Power is mostly done.
    Also added a first version of buffers to ftdi chip. I'll change the evtl.
    Started to route power section.
    [header.sch, ice40_breakout.kicad_pcb, ice40_breakout.sch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]
2019-05-06 Continued on Power PCB design
    [ice40_breakout.kicad_pcb, power.sch]
2019-05-07 Implemented proper Powerseparation between FTDI and FPGA. The old solution may not work correctly
    [ice40_breakout.kicad_pcb, progammer.sch]
2019-05-07 Continued on routing
    [ice40_breakout.kicad_pcb, progammer.sch]
2019-05-07 Continued on placing
    [ice40_breakout.kicad_pcb, progammer.sch]
2019-05-09 Continued with routing
    [header.sch, ice40_breakout.kicad_pcb, power.sch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]
2019-05-11 Continued with routing and added ADC
    [header.sch, ice40_breakout.kicad_pcb, ui.sch]
2019-05-12 Changed power isolation to usb power to use an open drain translator for the reset signals. Continued on routing
    [header.sch, ice40_breakout.kicad_pcb, power.sch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]
2019-05-12 Routing mostly done
    [ice40_breakout.kicad_pcb, progammer.sch]
2019-05-12 Added more BOM information, updated fpga symbol, added some more 3d models
    [header.sch, ice40_breakout.kicad_pcb, ice40_breakout.sch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]
2019-05-12 More BOM Information, more 3d Models
    [ice40_breakout.kicad_pcb, power.sch]
2019-05-14 Corrected a few footprints
    [header.sch, ice40_breakout.kicad_pcb, power.sch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]
2019-05-15 Finished Silkscreen and added layer markings as specified by manufacturer
    [header.sch, ice40_breakout.kicad_pcb, power.sch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]
2019-05-17 Fixed rotated PMODs
    [header.sch, ice40_breakout.kicad_pcb, ui.sch]
2019-05-17 New production data2
    [ice40_breakout-B_Cu.gbl, ice40_breakout-B_Mask.gbs, ice40_breakout-B_Paste.gbp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]
2019-05-17 refreshed schematic pdf
2019-05-22 More complete BOM
    [header.sch, ice40_breakout-BOM.csv, power.sch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]
2019-07-10 Add interactive BOM
